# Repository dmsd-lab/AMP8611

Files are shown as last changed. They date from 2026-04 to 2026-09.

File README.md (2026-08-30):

### AMP8611 - Integrated class AB Stereo Power Amplifier

Open hardware project under CERN-OHL-S v2 license
 
Amplifier combining a 2-channel input selector, 
PGA2311 digital volume control and 45W per-channel LM3886 output stages.  

Full documentation (description pdf, Kicad project schematic and PCB, Gerber files, BOM, STM32 firmware) is available in the repository.

**Key Specifications**:
- Input resistance: 10kΩ;  
- Nominal input voltage: 0.85Vrms;  
- Maximum input voltage: 2.5Vrms;  
- Input Channels isolation: 95dB;  
- Maximum output power: 2 x 45W RMS (1kHz sinusoidal, 4ohm load);  
- Bandwidth (-3dB): 20Hz – 90kHz;  
- Volume control: -80 to +12dB;  
- Dimensions: 240 x 265 x 65 mm (80 mm including feet);  
- Weight: 4.0 kg.

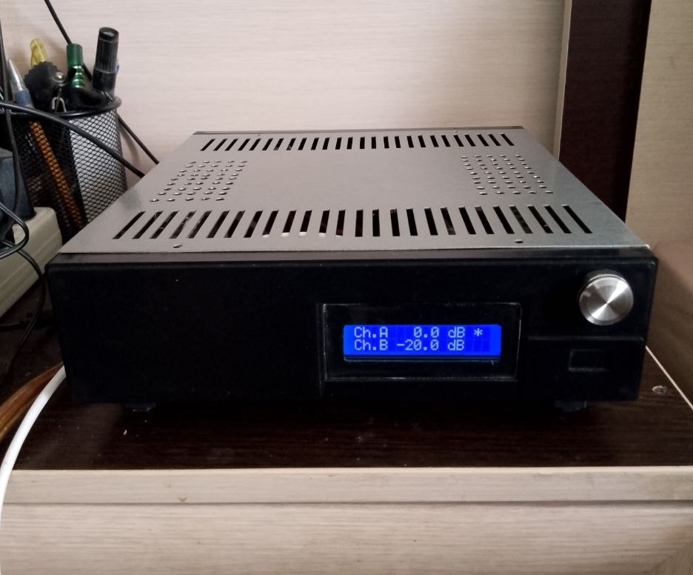
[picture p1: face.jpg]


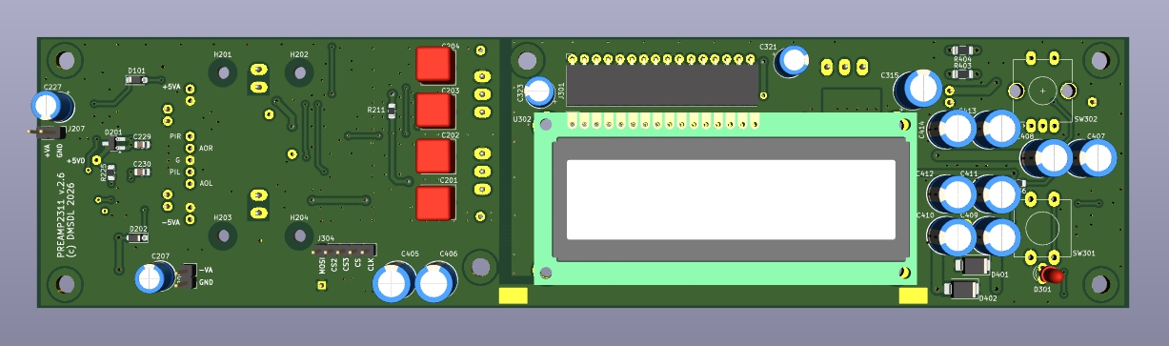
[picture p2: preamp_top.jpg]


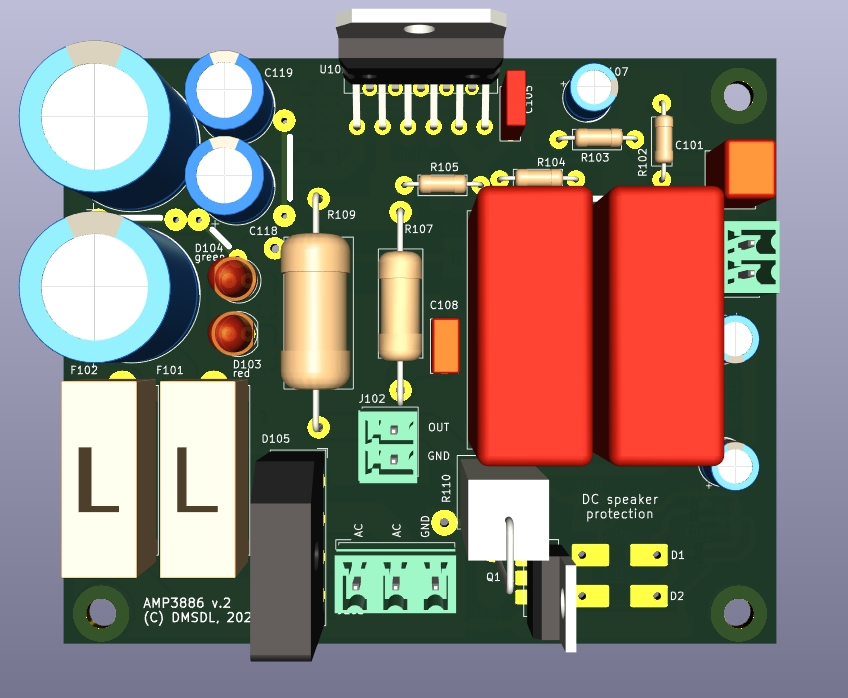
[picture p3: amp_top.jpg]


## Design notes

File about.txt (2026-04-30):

Integrated Stereo Power Amplifier with a 2-channel input selector, PGA2311 digital volume control and LM3886 power stages

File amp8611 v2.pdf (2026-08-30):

AMP8611 - Compact Integrated Stereo Power Amplifier

V.2.6
(c) DMSDL, 2026

Open hardware project released under CERN-OHL-S v2 license

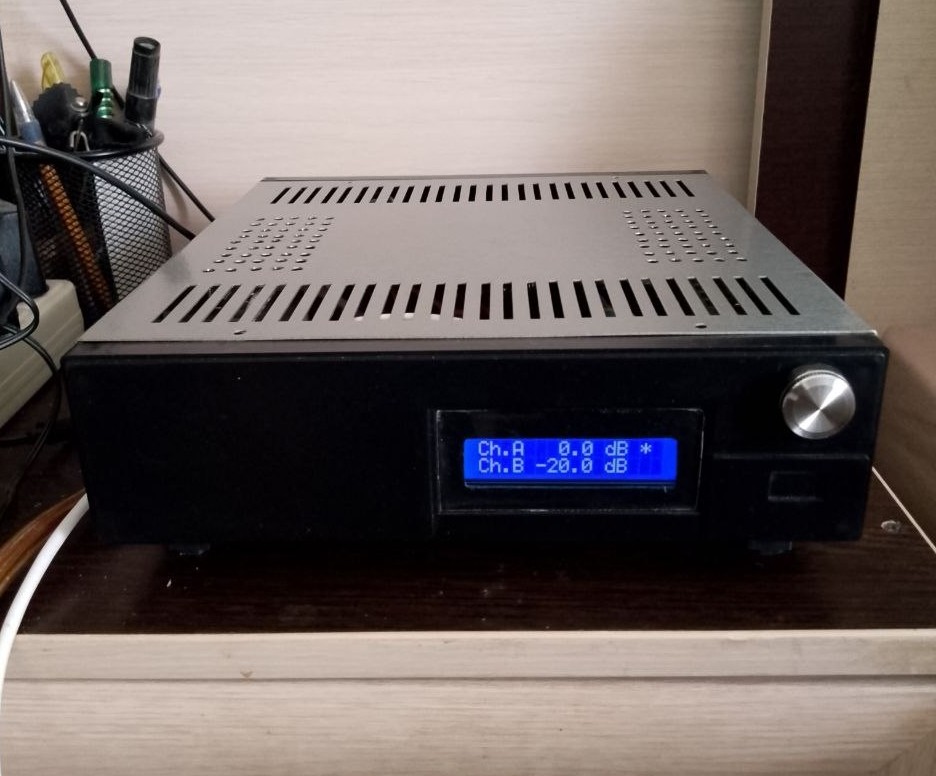
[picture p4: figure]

Amplifier combining a 2-channel input selector, high-performance PGA2311 digital volume control and LM3886 power stages.

Key Specifications:
Input resistance: 10kΩ;
Nominal input voltage: 0.85Vrms;
Maximum input voltage: 2.5Vrms;
Input Channels isolation: 95dB;
Maximum output power: 2 x 45W RMS (1kHz sinusoidal, 4ohm load); Bandwidth (-3dB): 20Hz – 90kHz;
Volume control: -80 to +12dB;
Dimensions: 240 x 265 x 65 mm (80 mm including feet);
Weight: 4.0 kg.

Full documentation (description PDF, schematic, PCB layout, Gerber files, BOM and firmware) is available in the repository https://github.com/dmsd-lab/AMP8611.

Preamplifier board PREAMP2311

Preamplifier based on PGA2311 - high-performance stereo volume control for professional and high-end consumer systems.
Input channel selector based on 74HCT4052 and OPA1678 in an ultra-low-distortion, seriesshunt current-mode configuration.
Bipolar power supply based on LM317L and LM337L linear regulators.
STM32G070 MCU, 2x16 LCD (with lowering backlight brightness after user inactivity)and rotary encoder with button for user interface (input channel selection, volume control).
Supports integration of controlled forced cooling and a digital tone control module.

Key Specifications:
Power supply: 2x(7 – 11V) AC or +-(8 – 14)V DC, 3W;
Input resistance: 10kΩ;
Maximum input voltage: 2.5Vrms;
Output offset voltage (gain 0dB), maximum: +-2.5mV;
Bandwidth (-3dB): 10Hz – 350kHz;
Channel isolation: 95dB;
Volume control: -80 to +12dB (−95.5 dB to +31.5 dB firmware limited); PCB dimensions: 234 x 58mm.

Firmware is developed with STM32CubeIDE.
The volume control step configuration is as follows:
−80 to −40dB - 5dB steps;
−40 to 0dB - 2dB steps;
0 to +12dB - 0.5dB steps.

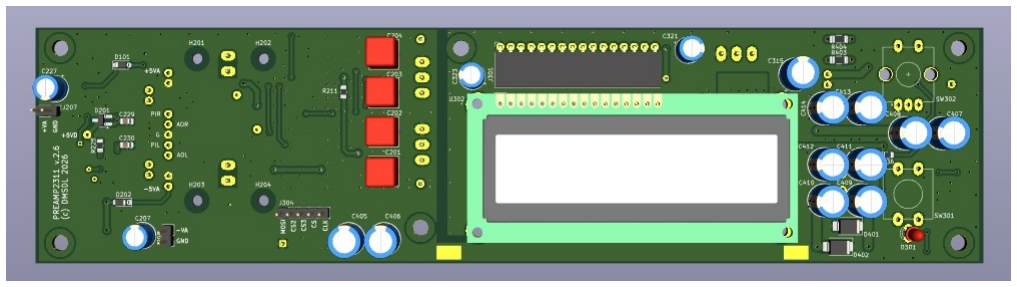
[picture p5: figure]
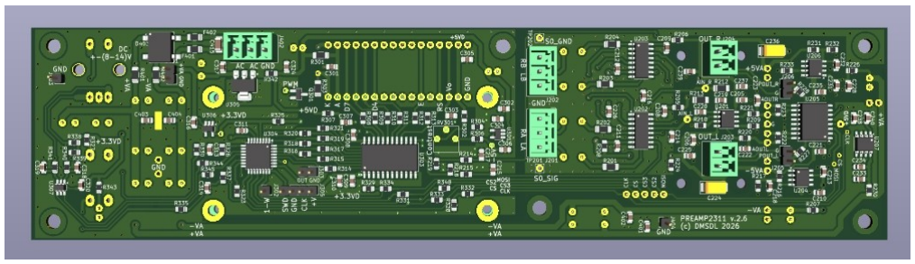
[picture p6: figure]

PREAMP2311 signal stage schematic

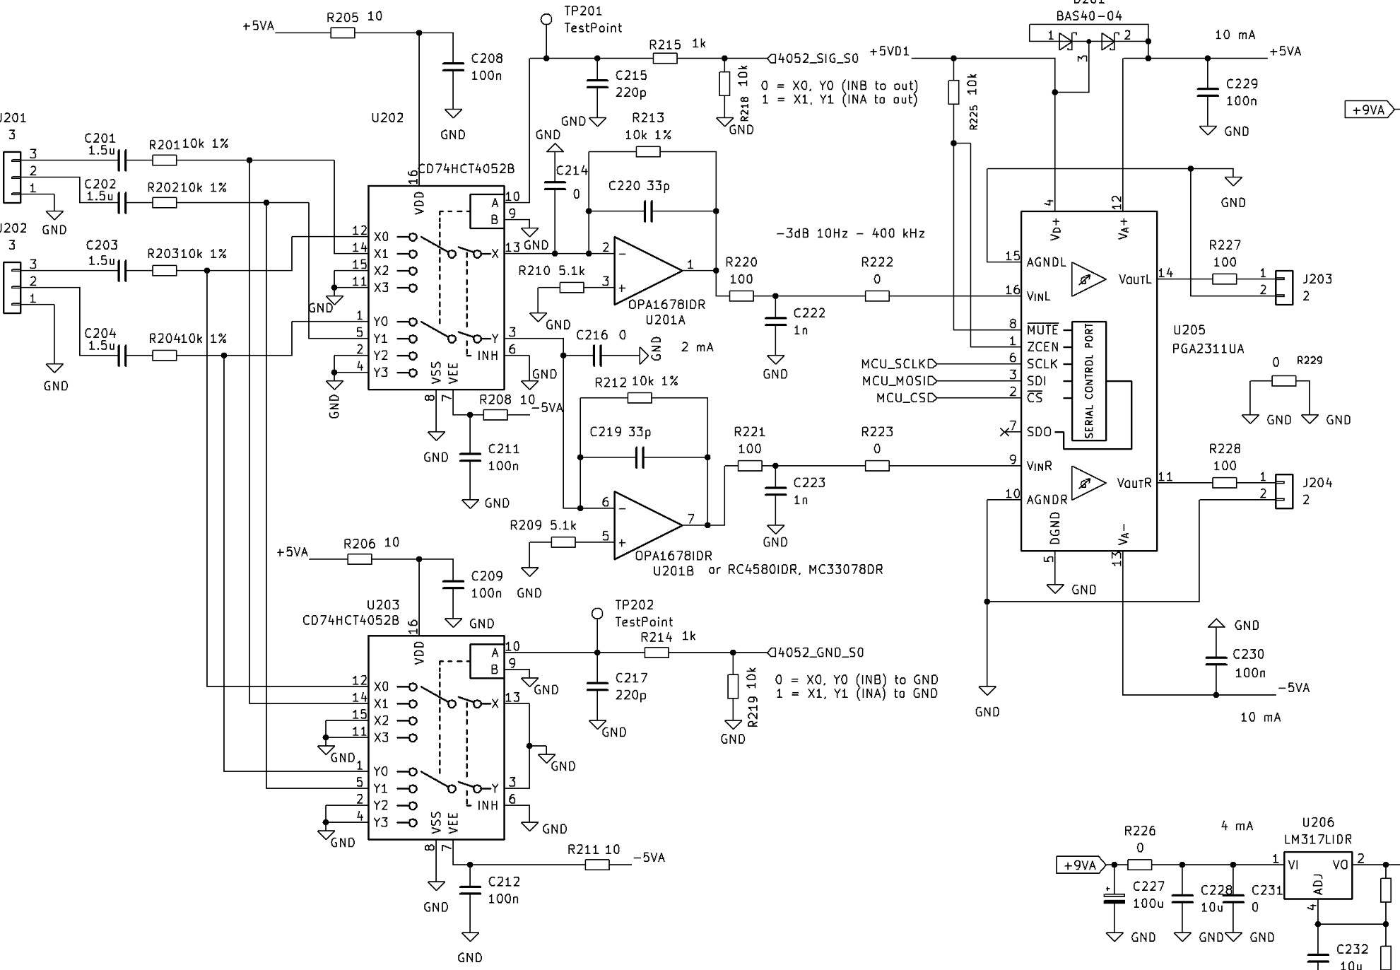
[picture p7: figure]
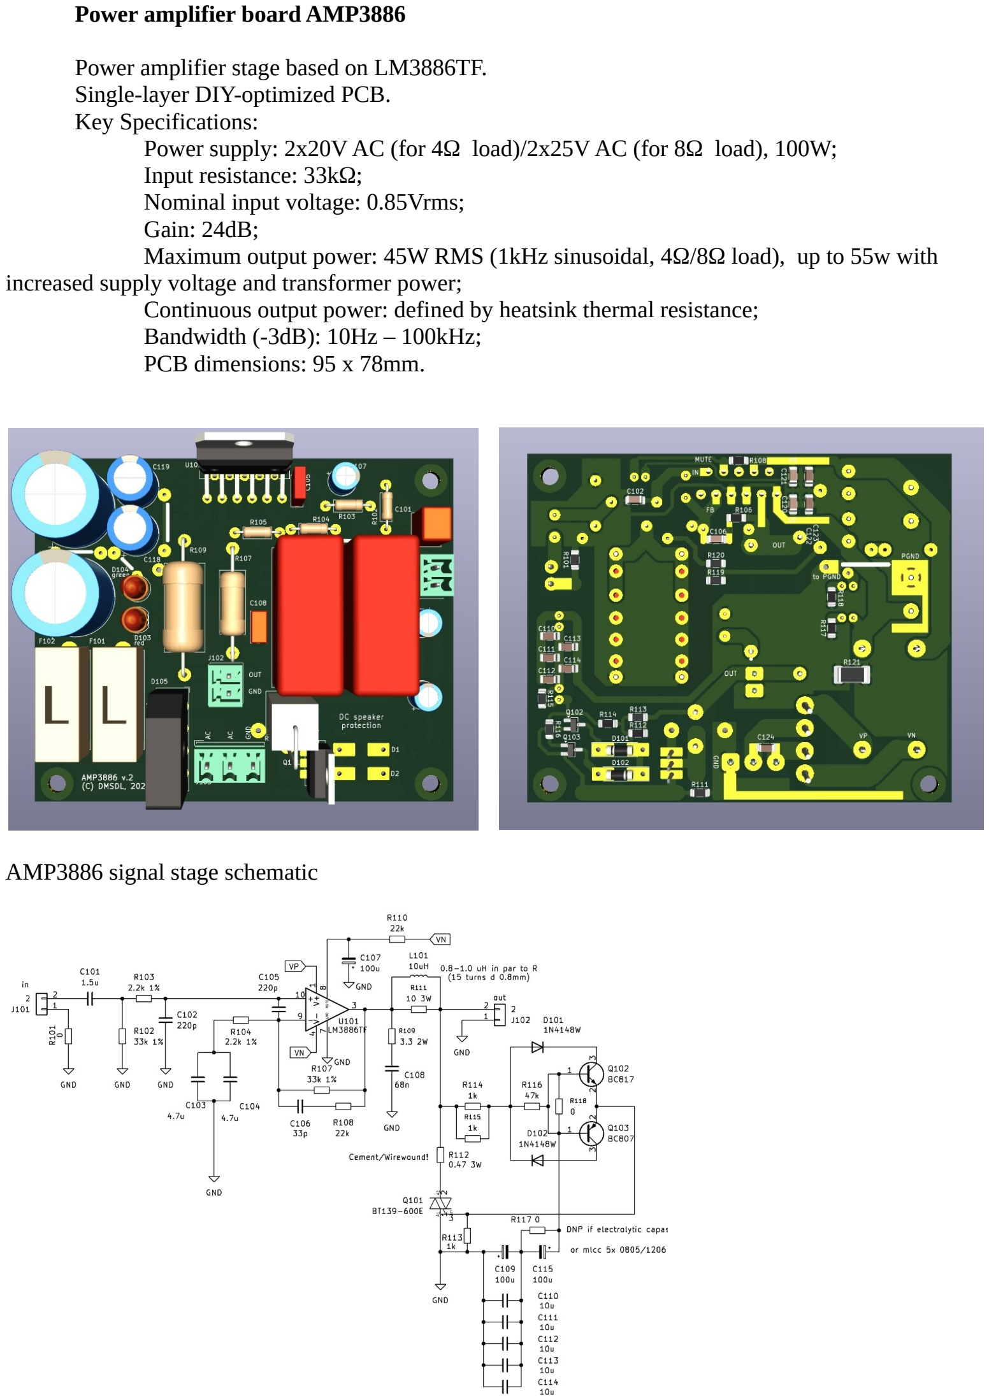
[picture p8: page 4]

Power amplifier board AMP3886

Power amplifier stage based on LM3886TF.
Single-layer DIY-optimized PCB.
Key Specifications:
Power supply: 2x20V AC (for 4Ω load)/2x25V AC (for 8Ω load), 100W; Input resistance: 33kΩ;
Nominal input voltage: 0.85Vrms;
Gain: 24dB;
Maximum output power: 45W RMS (1kHz sinusoidal, 4Ω/8Ω load), up to 55w with increased supply voltage and transformer power; Continuous output power: defined by heatsink thermal resistance;
Bandwidth (-3dB): 10Hz – 100kHz;
PCB dimensions: 95 x 78mm.

AMP3886 signal stage schematic

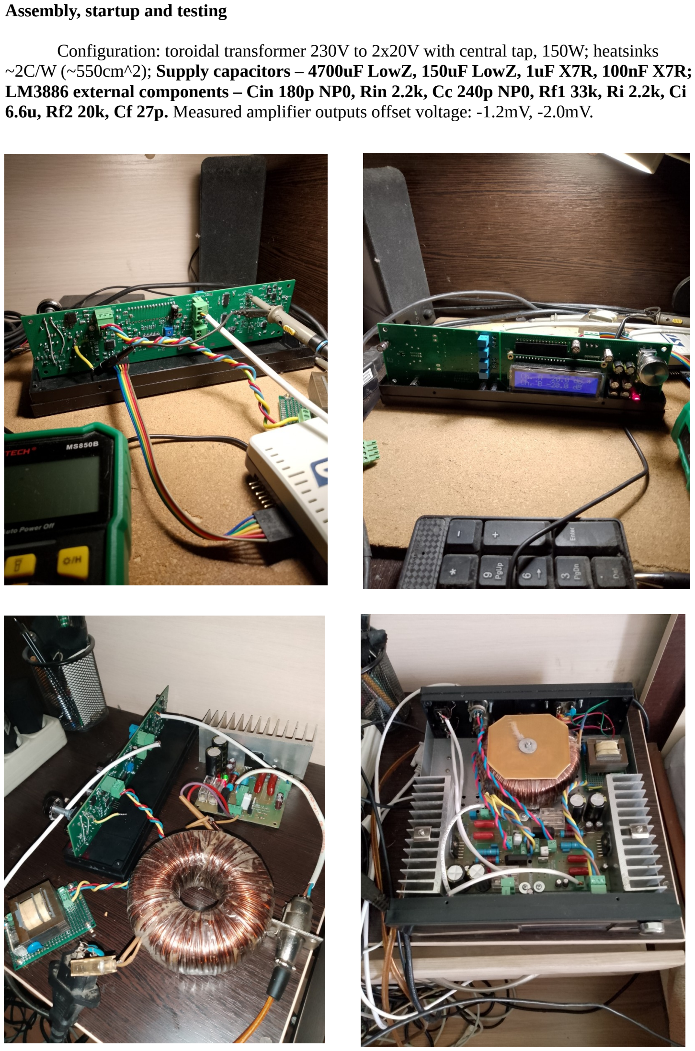
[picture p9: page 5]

Assembly, startup and testing

Configuration: toroidal transformer 230V to 2x20V with central tap, 150W; heatsinks ~2C/W (~550cm^2); Supply capacitors – 4700uF LowZ, 150uF LowZ, 1uF X7R, 100nF X7R; LM3886 external components – Cin 180p NP0, Rin 2.2k, Cc 240p NP0, Rf1 33k, Ri 2.2k, Ci 6.6u, Rf2 20k, Cf 27p. Measured amplifier outputs offset voltage: -1.2mV, -2.0mV.

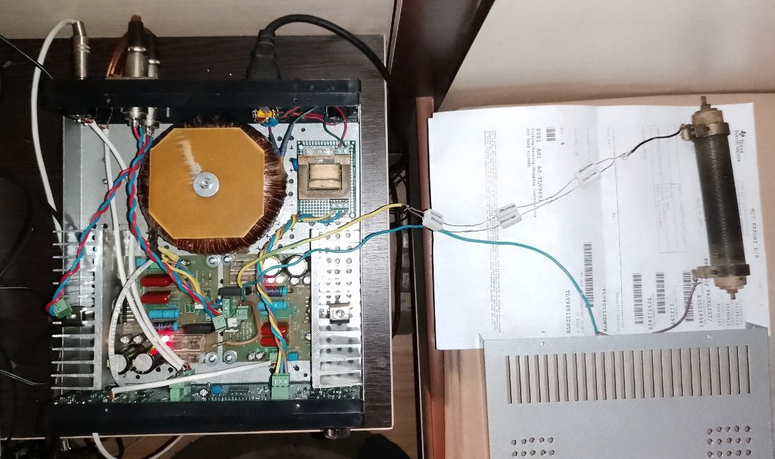
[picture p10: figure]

Caution: the protection circuit is provided as an optional safeguard. Its operation should be validated before soldering the amplifier IC.

Such a circuit was used in a Soviet amplifier “Орбита УМ-002”.

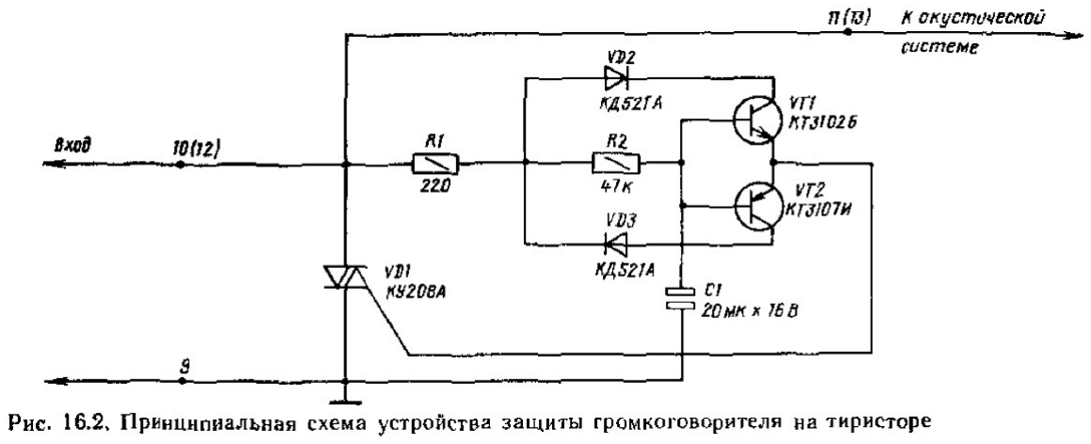
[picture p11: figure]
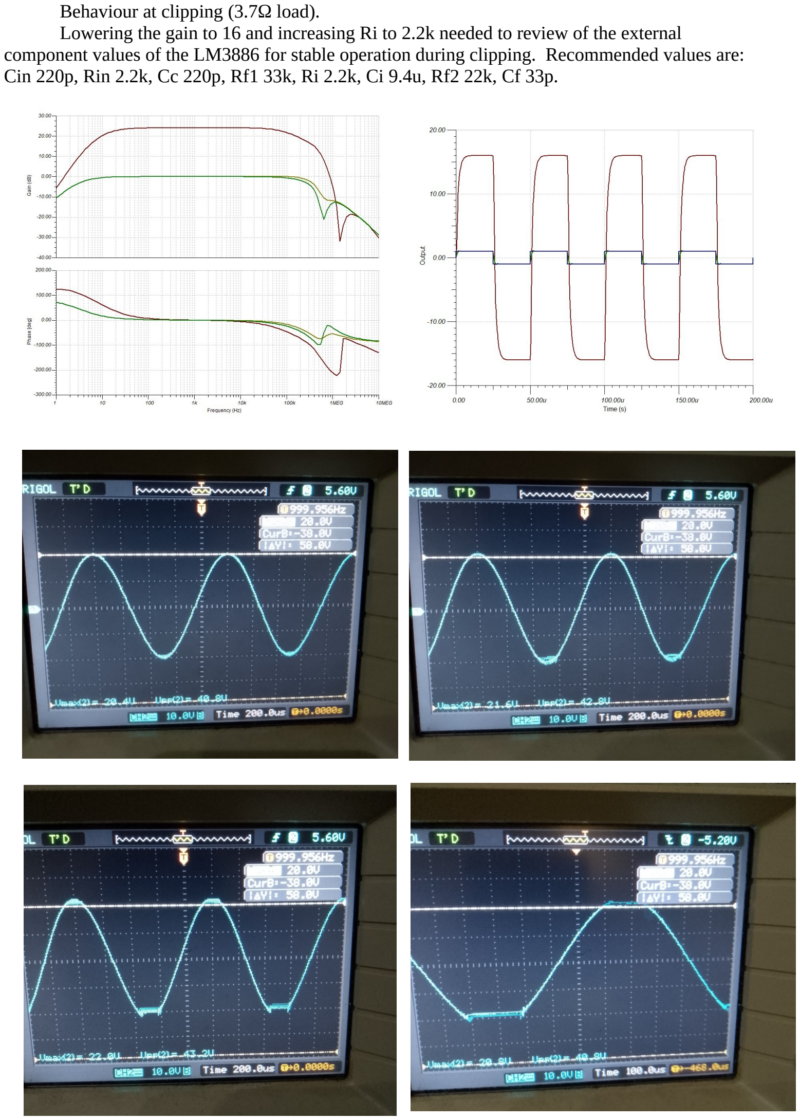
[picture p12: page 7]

Behaviour at clipping (3.7Ω load).
Lowering the gain to 16 and increasing Ri to 2.2k needed to review of the external component values of the LM3886 for stable operation during clipping. Recommended values are: Cin 220p, Rin 2.2k, Cc 220p, Rf1 33k, Ri 2.2k, Ci 9.4u, Rf2 22k, Cf 33p.

Output power test (3.7Ω load, 1kHz burst 20ms, 100Hz burst 100ms).

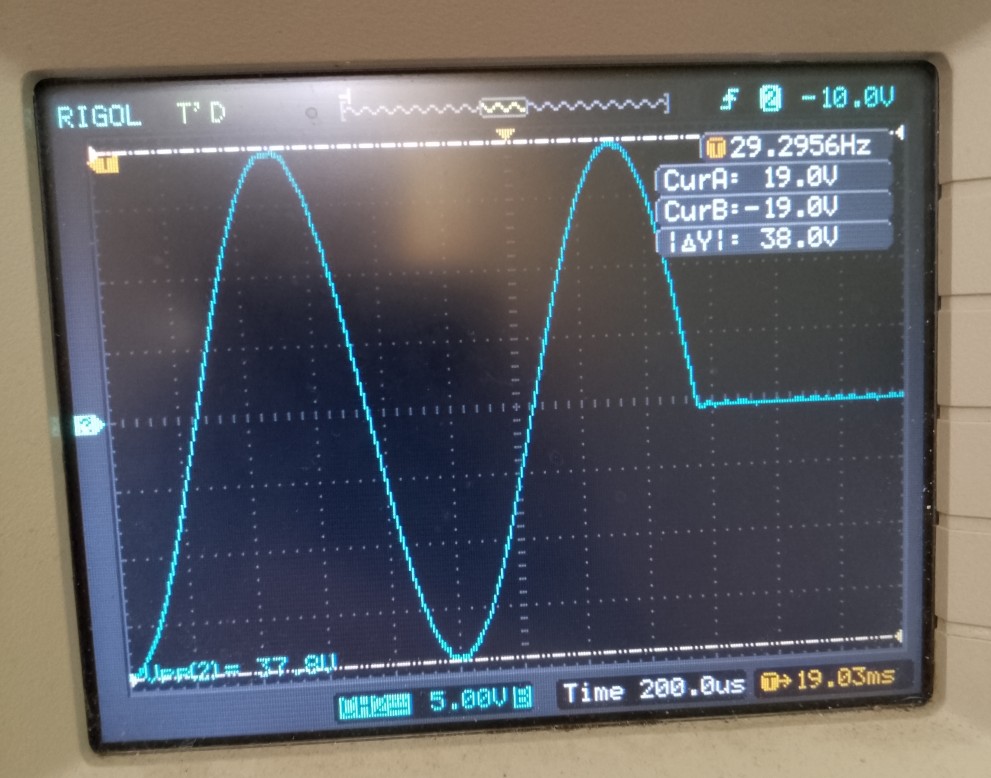
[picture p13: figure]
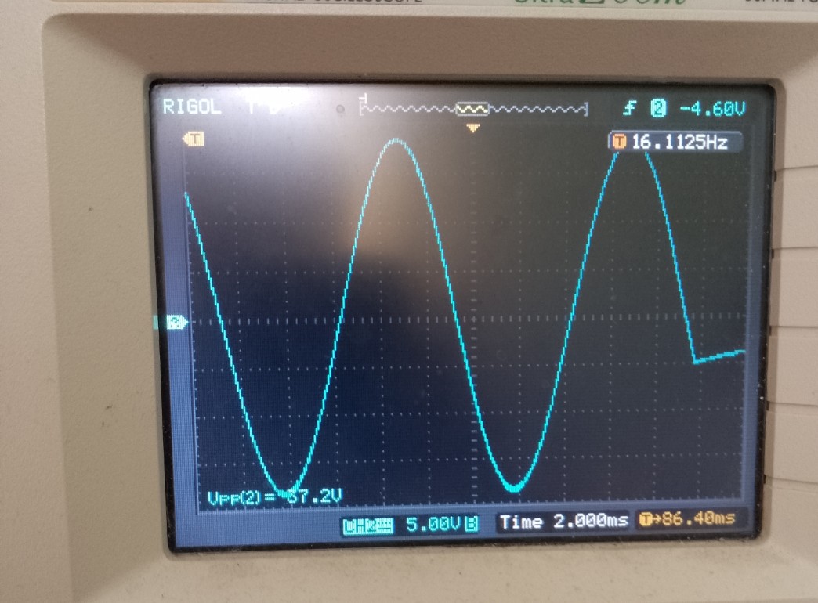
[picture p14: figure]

Musical signal test (3.7Ω load, PC audio output level 100% - 1V RMS when sinusoidal signal, volume control at 0dB).

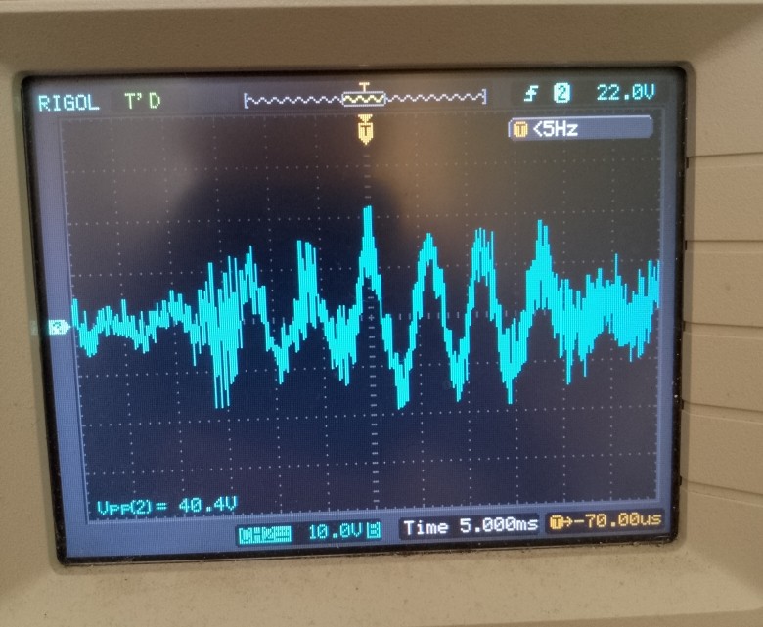
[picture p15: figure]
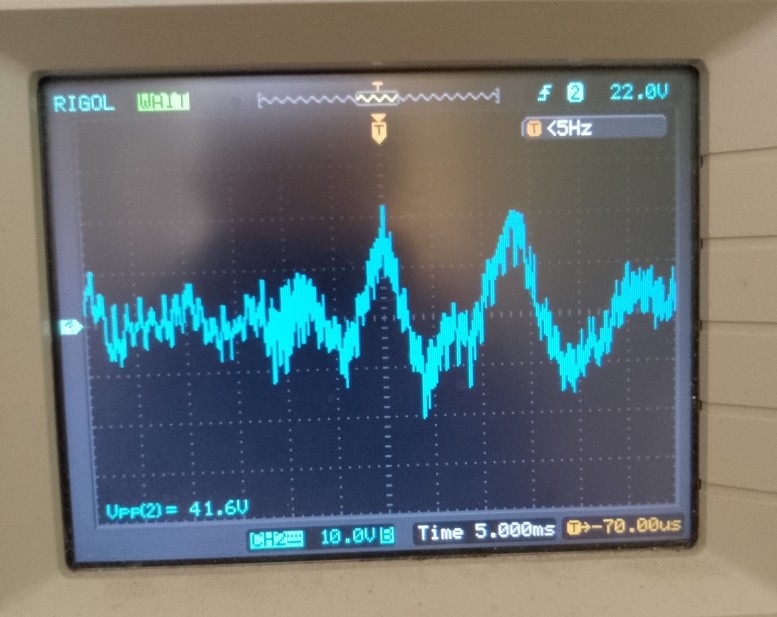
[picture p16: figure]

After 30 minutes of testing with a high density music signal (low crest factor) in a closed enclosure, ambient temperature 25C, the measured temperatures were:
- heatsink near the IC 75C;
- screw mounting the IC to the heatsink 80C.
In this mode, the amplifier already rarely clips the output signal at about 20V depending on the shape and power of the signal.
In the same operating mode, when driving a 4-ohm loudspeaker system, the temperatures is 10 degrees lower.
The amplifier is subjectively quiet: no audible mains hum or broadband noise at 50 cm from a 85dBw/m midbass driver in a quiet environment (volume at 0dB, input unconnected or PC output in sleep mode). With an active PC audio output, broadband noise becomes noticeable; at a volume setting of −10dB, the noise is barely distinguishable from the unconnected-input condition.

A working prototype (v. 1) was built and evaluated. The design met the intended specifications and no functional issues were observed.
The hardware released (v. 2) is a minor optimized revision of the prototype with no conceptual or architectural changes. A list of significant modifications is provided below.

Change log of preamplifier v.2.0 - 2.6:
1. Added resistor from the buffer op-amp non-inverting input to ground to compensate offset for op-amps with relatively high input bias currents;
2. Added MCU I/O for the 1-Wire interface, 3 output lines for control and 1 dedicated input for a button;
3. Removed the separate 3.3V voltage regulator for the 74LVC8T245 driver;
4. Added TVS diodes to the power input;
5. Added series resistors (10 - 100Ω) in the power lines of the multiplexers;
6. Added capacitor footprints to the multiplexer output (0-220pF for HF input noise and charge injection attenuation);
7. Reverse diode from output to input added to the LM317L and LM337L due to increased output capacitor value.

Change log of power amplifier v.2:
1. Added MLC capacitor footprints to the protection circuitry as alternative for electrolytic;
2. Pin 7 connected to SGND instead of connection to PGND.

Alternative components:
CD74HCT4052 – SOIC-16 CD74HC4052, 74HCT4052, 74HC4052, MC74HC4052A, MAX4052, MAX4582;
OPA1678IDR – OPA1688IDR, (https://www.ti.com/product/OPA1688/part-details/OPA1688ID) RC4580IDR, MC33078DR or any other with acceptable noise and distortion level (preferably with a lower overall output offset voltage);
TLV1117-50IDC – LM1117MPX-5.0, 5V SOT- 223 LD1117, NCP1117; TPS60403DBV – TPS60400DBV, TPS60401DBV, TPS60402DBV. Not needed if LCD offset voltage is positive.
SN74LVC8T245DW – SN74LVCC3245ADW;
SN74LVC2G17DBV – SN74LVC2G14DBV, 74HC2G17GV, 74HC2G14GV; 6800uF 35V 105C - 4700uF 35V 105C Low impedance.

Sources:
https://www.ti.com/product/LM3886
https://www.ti.com/product/PGA2311
https://www.ti.com/product/OPA1678

“Analog Switches and Multiplexers Basics” https://www.analog.com/media/en/trainingseminars/tutorials/MT-088.pdf (https://www.analog.com/media/en/training-seminars/tutorials/MT-088.pdf)
Douglas Self “Small signal audio design”, chapter 21 http://www.douglas-self.com/ampins/books/ssad3.htm
Samuel Groner “Operational amplifier distortion” 2009 https://audioxpress.com/article/modern-op-amp-distortion-tests-part-1-bjt-input-deviceshttps://audioxpress.com/article/modern-op-amp-distortion-tests-part-2-a-few-mo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 (https://audioxpress.com/article/modern-op-amp-distortion-tests-part-2-a-few-more-bjt-types-and-jfet-devices)
Атаев, Болотников “Функциональные узлы усилителей высококачественного звуковоспроизведения” 1989, chapter 16.3.
Rod Elliot, Crowbar Speaker Protection https://sound-au.com/project120.htm

© DMSDL, 2026
CERN-OHL-S v2 license

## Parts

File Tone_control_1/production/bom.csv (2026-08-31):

Designator | Footprint | Quantity | Value | LCSC Part #
C101, C102, C103, C105, C106, C107, C108, C111, C113, C124, C125, C134, C135 | 0805 | 13 | 100n
C104, C112 | 0805 | 2 | 10u
C109, C110 | CP_EIA-6032-20_AVX-F_HandSolder | 2 | 33u
C114, C115, C126, C129, C132, C133 | 0805 | 6 | 220p
C116, C117, C118, C120 | 0805 | 4 | 33p
C119, C121 | C_Rect_L7.5mm_W6.5mm_P5.00mm | 2 | 1,5u
C122, C123 | 0805 | 2 | 10n
C127, C128, C130, C131 | 1206 | 4 | 100n
D101, D102 | D_SOD-123 | 2 | 1N5819
J101 | PinHeader_1x01_P2.54mm_Vertical | 1 | Conn_01x01
J102 | PinSocket_1x12_P2.54mm_Vertical | 1 | Conn_01x05
J103 | PinSocket_1x05_P2.54mm_Vertical | 1 | Conn_01x05
R101, R102, R104, R106, R109, R110, R111, R112, R113, R114, R117, R118, R120, R122, R124, R126 | 0805 | 16 | 10k
R103, R105 | 0805 | 2 | 15k
R107, R108 | 0805 | 2 | 100
R115, R116, R119, R121, R123, R125 | 0805 | 6 | 3,3k
U101, U102, U103 | SOIC-8_3.9x4.9mm_P1.27mm | 3 | OPA1678
U104 | SOT-23-5_HandSoldering | 1 | TLV9051xDBV
U105, U106 | TSSOP-14_4.4x5mm_P0.65mm | 2 | MCP4261

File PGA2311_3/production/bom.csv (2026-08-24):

Designator | Footprint | Quantity | Value | LCSC Part #
C201, C202, C203, C204 | C_Rect_L7.2mm_W7.2mm_P5.00mm_FKS2_FKP2_MKS2_MKP2 | 4 | 1.5u
C205, C206, C208, C209, C211, C212, C221, C225, C226, C229, C230, C235, C237, C238, C239, C303, C309, C310, C311, C312, C313, C314, C318, C319, C320 | 0805 | 25 | 100n
C207, C227, C321, C323 | CP_Radial_D6.3mm_P2.50mm | 4 | 100u
C210, C218, C228, C232, C233, C240, C301, C302, C304, C305, C306, C307, C308, C316, C317, C322, C324, C401, C402, C403, C404 | 0805 | 21 | 10u
C213, C214, C216, C231, C234, R207, R222, R223, R226, R230, R304, R325 | 0805 | 12 | 0
C215, C217 | 0805 | 2 | 220p
C219, C220 | 0805 | 2 | 33p
C222, C223 | 0805 | 2 | 1n
C224, C236 | CP_EIA-6032-20_AVX-F_HandSolder | 2 | 33u
C315, C405, C406, C407, C408, C409, C410, C411, C412, C413, C414 | CP_Radial_D8.0mm_P3.50mm | 11 | 220u
C415 | 1206 | 1 | 100n
D101, D202 | D_SOD-123 | 2 | 1N5819
D201 | SOT-23_Handsoldering | 1 | BAS40-04
D301 | LED_D3.0mm | 1 | LED_GREEN
D401, D402 | D_SMB | 2 | SMAJ15.0A
D403 | Diode_Bridge_OnSemi_SDIP-4L | 1 | DF01S
F401, F402 | 1206 | 2 | MF-NSMF012-2
J201, J202, J402 | PhoenixContact_MCV_1,5_3-G-3.81_1x03_P3.81mm_Vertical | 3 | 3
J203, J204 | PhoenixContact_MCV_1,5_2-G-3.81_1x02_P3.81mm_Vertical | 2 | 2
J205, J206, J207, J208 | PinHeader_1x02_P2.54mm_Vertical | 4 | 2
J301 | PinSocket_1x16_P2.54mm_Horizontal | 1 | Conn_01x16
J302, J403, J404 | PinHeader_1x01_P2.54mm_Vertical | 3 | 1
J303 | PinHeader_1x02_P2.54mm_Vertical | 1 | Conn_01x02
J304 | PinHeader_1x05_P2.54mm_Vertical | 1 | 4
J305 | PinHeader_1x04_P2.54mm_Vertical | 1 | 4
J401 | PinHeader_1x02_P2.54mm_Vertical | 1 | 1
Q301 | SOT-23_Handsoldering | 1 | BC817-40
R201, R202, R203, R204, R212, R213 | 1206 | 6 | 10k 1%
R205, R206, R227, R228, R308, R309, R310, R311, R312, R313, R314, R315, R316, R317, R318, R319, R320, R321 | 0805 | 18 | 100
R208, R211 | 0805 | 2 | 10
R209, R210 | 0805 | 2 | 5.1k
R214, R215, R224, R233, R323, R326, R327, R331, R332, R333, R334, R336, R337, R338, R339, R344, R345, R348 | 0805 | 18 | 1k
R216, R231 | 0805 | 2 | 330 1%
R217, R232 | 0805 | 2 | 1k 1%
R218, R219, R225, R328, R329, R330, R335, R340, R341, R346, R347, R349 | 0805 | 12 | 10k
R220, R221, R343 | 0805 | 3 | 220
R301, R401, R402 | 1206 | 3 | 1
R302, R306 | 0805 | 2 | 2.7k
R303 | 1206 | 1 | 100
R305, R322, R324 | 0805 | 3 | 2,7k
R307, R342 | 0805 | 2 | 0.33
R403, R404 | 1206 | 2 | 0
RV301 | Potentiometer_Vishay_T73YP_Vertical | 1 | KLS4-3362P 5.1k
SW301 | SW_PUSH-12mm | 1 | SW_Push
SW302 | RotaryEncoder_Alps_EC12E-Switch_Vertical_H20mm_CircularMountingHoles | 1 | Encoder PEC11R
TP201, TP202 | TestPoint_THTPad_2.0x2.0mm_Drill1.0mm | 2 | TestPoint
U201 | SOIC-8_3.9x4.9mm_P1.27mm | 1 | OPA1678IDR
U202, U203 | SOIC-16_3.9x9.9mm_P1.27mm | 2 | CD74HCT4052
U204 | SOIC-8_3.9x4.9mm_P1.27mm | 1 | LM337LM
U205 | SOIC-16W_7.5x10.3mm_P1.27mm | 1 | PGA2311UA
U206 | SOIC-8_3.9x4.9mm_P1.27mm | 1 | LM317LIDR
U207 | SOIC-8_3.9x4.9mm_P1.27mm | 1 | UA78L05AIDR
U301 | SOT-23-5_HandSoldering | 1 | TPS60403DBV
U302 | WC1602A | 1 | WH1602B
U303 | SOIC-24W_7.5x15.4mm_P1.27mm | 1 | SN74LVC8T245DW
U304 | LQFP-32_7x7mm_P0.8mm | 1 | STM32G070KBT6
U305 | SOT-223-3_TabPin2 | 1 | TLV1117-50IDC
U306 | SOT-23-5_HandSoldering | 1 | LP2985-33DBV
U307 | SOT-23-6_Handsoldering | 1 | SN74LVC2G17DBV

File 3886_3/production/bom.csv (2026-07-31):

Designator | Footprint | Quantity | Value | LCSC Part #
C101 | C_Rect_L7.5mm_W6.5mm_P5.00mm | 1 | 1.5u
C102 | 1206 | 1 | 220p
C103, C104 | C_Rect_L31.5mm_W13.0mm_P27.50mm_MKS4 | 2 | 4.7u
C105 | C_Rect_L7.0mm_W2.5mm_P5.00mm | 1 | 220p
C106 | 1206 | 1 | 33p
C107, C109, C115 | CP_Radial_D6.3mm_P2.50mm | 3 | 100u
C108 | C_Rect_L7.0mm_W3.5mm_P5.00mm | 1 | 68n
C110, C111, C112, C113, C114 | 1206 | 5 | 10u
C116, C117 | CP_Radial_D18.0mm_P7.50mm | 2 | 6800u
C118, C119 | CP_Radial_D10.0mm_P5.00mm | 2 | 470u
C120, C121 | 1206 | 2 | 100n
C122, C123 | 1206 | 2 | 1u
C124 | 1206 | 1 | 100n 100V
D101, D102 | D_MELF-RM10_Universal_Handsoldering | 2 | 1N4148W
D103 | LED_D5.0mm | 1 | LED red
D104 | LED_D5.0mm | 1 | LED green
D105 | Diode_Bridge_Vishay_KBU | 1 | KBU1010
F101, F102 | Fuseholder_Cylinder-5x20mm_Stelvio-Kontek_PTF78_Horizontal_Open | 2 | 3A
J101, J102 | PhoenixContact_MCV_1,5_2-G-3.81_1x02_P3.81mm_Vertical | 2 | 2
J103 | PhoenixContact_MCV_1,5_3-G-5.08_1x03_P5.08mm_Vertical | 1 | 3
Q101 | TO-220-3_Vertical | 1 | BT139-600E
Q102 | SOT-23_Handsoldering | 1 | BC817
Q103 | SOT-23_Handsoldering | 1 | BC807
R101, R115, R116 | 1206 | 3 | 0
R102, R105 | R_Axial_DIN0207_L6.3mm_D2.5mm_P10.16mm_Horizontal | 2 | 33k 1%
R103, R104 | R_Axial_DIN0207_L6.3mm_D2.5mm_P10.16mm_Horizontal | 2 | 2.2k 1%
R106, R108 | 1206 | 2 | 22k
R107 | R_Axial_DIN0614_L14.3mm_D5.7mm_P25.40mm_Horizontal | 1 | 3.3 2W
R109 | R_Axial_DIN0922_L20.0mm_D9.0mm_P30.48mm_Horizontal | 1 | 10 3W
R110 | R_Axial_Power_L25.0mm_W9.0mm_P7.62mm_Vertical | 1 | 0.47 3W
R111, R112, R113 | 1206 | 3 | 1k
R114 | 1206 | 1 | 47k
R117, R118 | 1206 | 2 | 10k
R119, R120 | 1206 | 2 | 1
R121 | 2512 | 1 | 0
U101 | TO-220-11_P3.4x5.08mm_StaggerOdd_Lead4.58mm_Vertical | 1 | LM3886TF

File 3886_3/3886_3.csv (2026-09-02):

Id | Designator | Footprint | Quantity | Designation | Supplier and ref
1 | R104,R103 | R_Axial_DIN0207_L6.3mm_D2.5mm_P10.16mm_Horizontal | 2 | 2.2k 1%
2 | C115,C109,C107 | CP_Radial_D6.3mm_P2.50mm | 3 | 100u
3 | C104,C103 | C_Rect_L31.5mm_W13.0mm_P27.50mm_MKS4 | 2 | 4.7u
4 | D105 | Diode_Bridge_Vishay_KBU | 1 | KBU1010
5 | J103 | PhoenixContact_MCV_1,5_3-G-5.08_1x03_P5.08mm_Vertical | 1 | 3
6 | D104 | LED_D5.0mm | 1 | LED green
7 | U101 | TO-220-11_P3.4x5.08mm_StaggerOdd_Lead4.58mm_Vertical | 1 | LM3886TF
8 | D103 | LED_D5.0mm | 1 | LED red
9 | R102,R105 | R_Axial_DIN0207_L6.3mm_D2.5mm_P10.16mm_Horizontal | 2 | 33k 1%
10 | R109 | R_Axial_DIN0922_L20.0mm_D9.0mm_P30.48mm_Horizontal | 1 | 10 3W
11 | Q101 | TO-220-3_Vertical | 1 | BT139-600E
12 | C108 | C_Rect_L7.0mm_W3.5mm_P5.00mm | 1 | 68n
13 | F101,F102 | Fuseholder_Cylinder-5x20mm_Stelvio-Kontek_PTF78_Horizontal_Open | 2 | 3A
14 | C119,C118 | CP_Radial_D10.0mm_P5.00mm | 2 | 470u
15 | C116,C117 | CP_Radial_D18.0mm_P7.50mm | 2 | 6800u
16 | R107 | R_Axial_DIN0614_L14.3mm_D5.7mm_P25.40mm_Horizontal | 1 | 3.3 2W
17 | R110 | R_Axial_Power_L25.0mm_W9.0mm_P7.62mm_Vertical | 1 | 0.47 3W
18 | J101,J102 | PhoenixContact_MCV_1,5_2-G-3.81_1x02_P3.81mm_Vertical | 2 | 2
19 | C105 | C_Rect_L7.0mm_W2.5mm_P5.00mm | 1 | 220p
20 | C101 | C_Rect_L7.5mm_W6.5mm_P5.00mm | 1 | 1.5u
21 | R120,R119 | R_1206_3216Metric_Pad1.30x1.75mm_HandSolder | 2 | 1
22 | C102 | C_1206_3216Metric_Pad1.33x1.80mm_HandSolder | 1 | 220p
23 | R115,R116,R101 | R_1206_3216Metric_Pad1.30x1.75mm_HandSolder | 3 | 0
24 | R117,R118 | R_1206_3216Metric_Pad1.30x1.75mm_HandSolder | 2 | 10k
25 | R108,R106 | R_1206_3216Metric_Pad1.30x1.75mm_HandSolder | 2 | 22k
26 | R114 | R_1206_3216Metric_Pad1.30x1.75mm_HandSolder | 1 | 47k
27 | C121,C120 | C_1206_3216Metric_Pad1.33x1.80mm_HandSolder | 2 | 100n
28 | C111,C110,C113,C114,C112 | C_1206_3216Metric_Pad1.33x1.80mm_HandSolder | 5 | 10u
29 | D102,D101 | D_MELF-RM10_Universal_Handsoldering | 2 | 1N4148W
30 | C123,C122 | C_1206_3216Metric_Pad1.33x1.80mm_HandSolder | 2 | 1u
31 | R113,R111,R112 | R_1206_3216Metric_Pad1.30x1.75mm_HandSolder | 3 | 1k
32 | Q102 | SOT-23_Handsoldering | 1 | BC817
33 | R121 | R_2512_6332Metric_Pad1.40x3.35mm_HandSolder | 1 | 0
34 | Q103 | SOT-23_Handsoldering | 1 | BC807
35 | C124 | C_1206_3216Metric_Pad1.33x1.80mm_HandSolder | 1 | 100n 100V
36 | C106 | C_1206_3216Metric_Pad1.33x1.80mm_HandSolder | 1 | 33p

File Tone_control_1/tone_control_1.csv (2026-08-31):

Id | Designator | Footprint | Quantity | Designation | Supplier and ref
1 | D101,D102 | D_SOD-123 | 2 | 1N5819
2 | U106,U105 | TSSOP-14_4.4x5mm_P0.65mm | 2 | MCP4261
3 | C112,C104 | C_0805_2012Metric_Pad1.18x1.45mm_HandSolder | 2 | 10u
4 | R124,R101,R120,R102,R113,R109,R114,R106,R110,R111,R118,R112,R117,R104,R122,R126 | R_0805_2012Metric_Pad1.20x1.40mm_HandSolder | 16 | 10k
5 | R103,R105 | R_0805_2012Metric_Pad1.20x1.40mm_HandSolder | 2 | 15k
6 | C124,C106,C111,C107,C108,C102,C103,C135,C101,C125,C134,C105,C113 | C_0805_2012Metric_Pad1.18x1.45mm_HandSolder | 13 | 100n
7 | R125,R121,R123,R119,R116,R115 | R_0805_2012Metric_Pad1.20x1.40mm_HandSolder | 6 | 3,3k
8 | U103,U101,U102 | SOIC-8_3.9x4.9mm_P1.27mm | 3 | OPA1678
9 | U104 | SOT-23-5_HandSoldering | 1 | TLV9051xDBV
10 | C120,C118,C116,C117 | C_0805_2012Metric_Pad1.18x1.45mm_HandSolder | 4 | 33p
11 | R107,R108 | R_0805_2012Metric_Pad1.20x1.40mm_HandSolder | 2 | 100
12 | C127,C130,C131,C128 | C_1206_3216Metric_Pad1.33x1.80mm_HandSolder | 4 | 100n
13 | C122,C123 | C_0805_2012Metric_Pad1.18x1.45mm_HandSolder | 2 | 10n
14 | J103 | PinSocket_1x05_P2.54mm_Vertical | 1 | Conn_01x05
15 | C133,C114,C126,C115,C132,C129 | C_0805_2012Metric_Pad1.18x1.45mm_HandSolder | 6 | 220p
16 | C110,C109 | CP_EIA-6032-20_AVX-F_HandSolder | 2 | 33u
17 | C121,C119 | C_Rect_L7.5mm_W6.5mm_P5.00mm | 2 | 1,5u
18 | J101 | PinHeader_1x01_P2.54mm_Vertical | 1 | Conn_01x01
19 | J102 | PinSocket_1x12_P2.54mm_Vertical | 1 | Conn_01x05

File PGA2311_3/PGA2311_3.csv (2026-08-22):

Id | Designator | Footprint | Quantity | Designation | Supplier and ref
1 | U302 | WC1602A | 1 | WH1602B
2 | J208,J207,J206,J205 | PinHeader_1x02_P2.54mm_Vertical | 4 | 2
3 | C321,C323,C227,C207 | CP_Radial_D6.3mm_P2.50mm | 4 | 100u
4 | SW301 | SW_PUSH-12mm | 1 | SW_Push
5 | C413,C410,C405,C412,C409,C315,C406,C411,C407,C414,C408 | CP_Radial_D8.0mm_P3.50mm | 11 | 220u
6 | R404,R403 | R_1206_3216Metric_Pad1.30x1.75mm_HandSolder | 2 | 0
7 | D301 | LED_D3.0mm | 1 | LED_GREEN
8 | D402,D401 | D_SMB | 2 | SMAJ15.0A
9 | C312,C229,C230,C206,C205,C310,C226,C238,C239,C209,C303,C318,C208,C211,C235,C314,C221,C225,C309,C311,C320,C237,C313,C319,C212 | C_0805_2012Metric_Pad1.18x1.45mm_HandSolder | 25 | 100n
10 | C322,C324,C228,C301,C403,C210,C401,C218,C302,C308,C240,C307,C404,C402,C232,C317,C306,C305,C233,C316,C304 | C_0805_2012Metric_Pad1.18x1.45mm_HandSolder | 21 | 10u
11 | R349,R225,R347,R346,R340,R341,R330,R219,R218,R335,R329,R328 | R_0805_2012Metric_Pad1.20x1.40mm_HandSolder | 12 | 10k
12 | R336,R224,R334,R332,R337,R214,R233,R331,R215,R339,R327,R345,R326,R323,R333,R344,R348,R338 | R_0805_2012Metric_Pad1.20x1.40mm_HandSolder | 18 | 1k
13 | SW302 | RotaryEncoder_Alps_EC12E-Switch_Vertical_H20mm_CircularMountingHoles | 1 | Encoder PEC11R
14 | C201,C204,C203,C202 | C_Rect_L7.2mm_W7.2mm_P5.00mm_FKS2_FKP2_MKS2_MKP2 | 4 | 1.5u
15 | R322,R324,R305 | R_0805_2012Metric_Pad1.20x1.40mm_HandSolder | 3 | 2,7k
16 | D201 | SOT-23_Handsoldering | 1 | BAS40-04
17 | R211,R208 | R_0805_2012Metric_Pad1.20x1.40mm_HandSolder | 2 | 10
18 | J304 | PinHeader_1x05_P2.54mm_Vertical | 1 | 4
19 | J301 | PinSocket_1x16_P2.54mm_Horizontal | 1 | Conn_01x16
20 | C219,C220 | C_0805_2012Metric_Pad1.18x1.45mm_HandSolder | 2 | 33p
21 | R232,R217 | R_0805_2012Metric_Pad1.20x1.40mm_HandSolder | 2 | 1k 1%
22 | U305 | SOT-223-3_TabPin2 | 1 | TLV1117-50IDC
23 | C222,C223 | C_0805_2012Metric_Pad1.18x1.45mm_HandSolder | 2 | 1n
24 | R313,R320,R312,R314,R228,R309,R227,R319,R315,R311,R316,R321,R308,R317,R318,R205,R206,R310 | R_0805_2012Metric_Pad1.20x1.40mm_HandSolder | 18 | 100
25 | C236,C224 | CP_EIA-6032-20_AVX-F_HandSolder | 2 | 22u
26 | C215,C217 | C_0805_2012Metric_Pad1.18x1.45mm_HandSolder | 2 | 220p
27 | J202,J402,J201 | PhoenixContact_MCV_1,5_3-G-3.81_1x03_P3.81mm_Vertical | 3 | 3
28 | C234,C213,C216,C214,C231 | C_0805_2012Metric_Pad1.18x1.45mm_HandSolder | 5 | 0
29 | R210,R209 | R_0805_2012Metric_Pad1.20x1.40mm_HandSolder | 2 | 5.1k
30 | U304 | LQFP-32_7x7mm_P0.8mm | 1 | STM32G070KBT6
31 | F402,F401 | Fuse_1206_3216Metric | 2 | MF-NSMF012-2
32 | J305 | PinHeader_1x04_P2.54mm_Vertical | 1 | 4
33 | D403 | Diode_Bridge_OnSemi_SDIP-4L | 1 | DF01S
34 | R201,R212,R202,R204,R203,R213 | R_1206_3216Metric_Pad1.30x1.75mm_HandSolder | 6 | 10k 1%
35 | U307 | SOT-23-6_Handsoldering | 1 | SN74LVC2G17DBV
36 | R220,R343,R221 | R_0805_2012Metric_Pad1.20x1.40mm_HandSolder | 3 | 220
37 | U303 | SOIC-24W_7.5x15.4mm_P1.27mm | 1 | SN74LVC8T245DW
38 | R303 | R_1206_3216Metric_Pad1.30x1.75mm_HandSolder | 1 | 100
39 | R342,R307 | R_0805_2012Metric_Pad1.20x1.40mm_HandSolder | 2 | 0.33
40 | J303 | PinHeader_1x02_P2.54mm_Vertical | 1 | Conn_01x02
41 | U301 | SOT-23-5_HandSoldering | 1 | TPS60403DBV
42 | R230,R222,R325,R207,R226,R304,R223 | R_0805_2012Metric_Pad1.20x1.40mm_HandSolder | 7 | 0
43 | R306,R302 | R_0805_2012Metric_Pad1.20x1.40mm_HandSolder | 2 | 2.7k
44 | U206 | SOIC-8_3.9x4.9mm_P1.27mm | 1 | LM317LIDR
45 | R216,R231 | R_0805_2012Metric_Pad1.20x1.40mm_HandSolder | 2 | 330 1%
46 | Q301 | SOT-23_Handsoldering | 1 | BC817-40
47 | R301,R402,R401 | R_1206_3216Metric_Pad1.30x1.75mm_HandSolder | 3 | 1
48 | J302,J403,J404 | PinHeader_1x01_P2.54mm_Vertical | 3 | 1
49 | TP201,TP202 | TestPoint_THTPad_2.0x2.0mm_Drill1.0mm | 2 | TestPoint
50 | U306 | SOT-23-5_HandSoldering | 1 | LP2985-33DBV
51 | RV301 | Potentiometer_Vishay_T73YP_Vertical | 1 | KLS4-3362P 5.1k
52 | C415 | C_1206_3216Metric_Pad1.33x1.80mm_HandSolder | 1 | 100n
53 | U207 | SOIC-8_3.9x4.9mm_P1.27mm | 1 | UA78L05AIDR
54 | U203,U202 | SOIC-16_3.9x9.9mm_P1.27mm | 2 | CD74HCT4052
55 | J204,J203 | PhoenixContact_MCV_1,5_2-G-3.81_1x02_P3.81mm_Vertical | 2 | 2
56 | J401 | PinHeader_1x02_P2.54mm_Vertical | 1 | 1
57 | U204 | SOIC-8_3.9x4.9mm_P1.27mm | 1 | LM337LM
58 | U205 | SOIC-16W_7.5x10.3mm_P1.27mm | 1 | PGA2311UA
59 | U201 | SOIC-8_3.9x4.9mm_P1.27mm | 1 | OPA1678IDR

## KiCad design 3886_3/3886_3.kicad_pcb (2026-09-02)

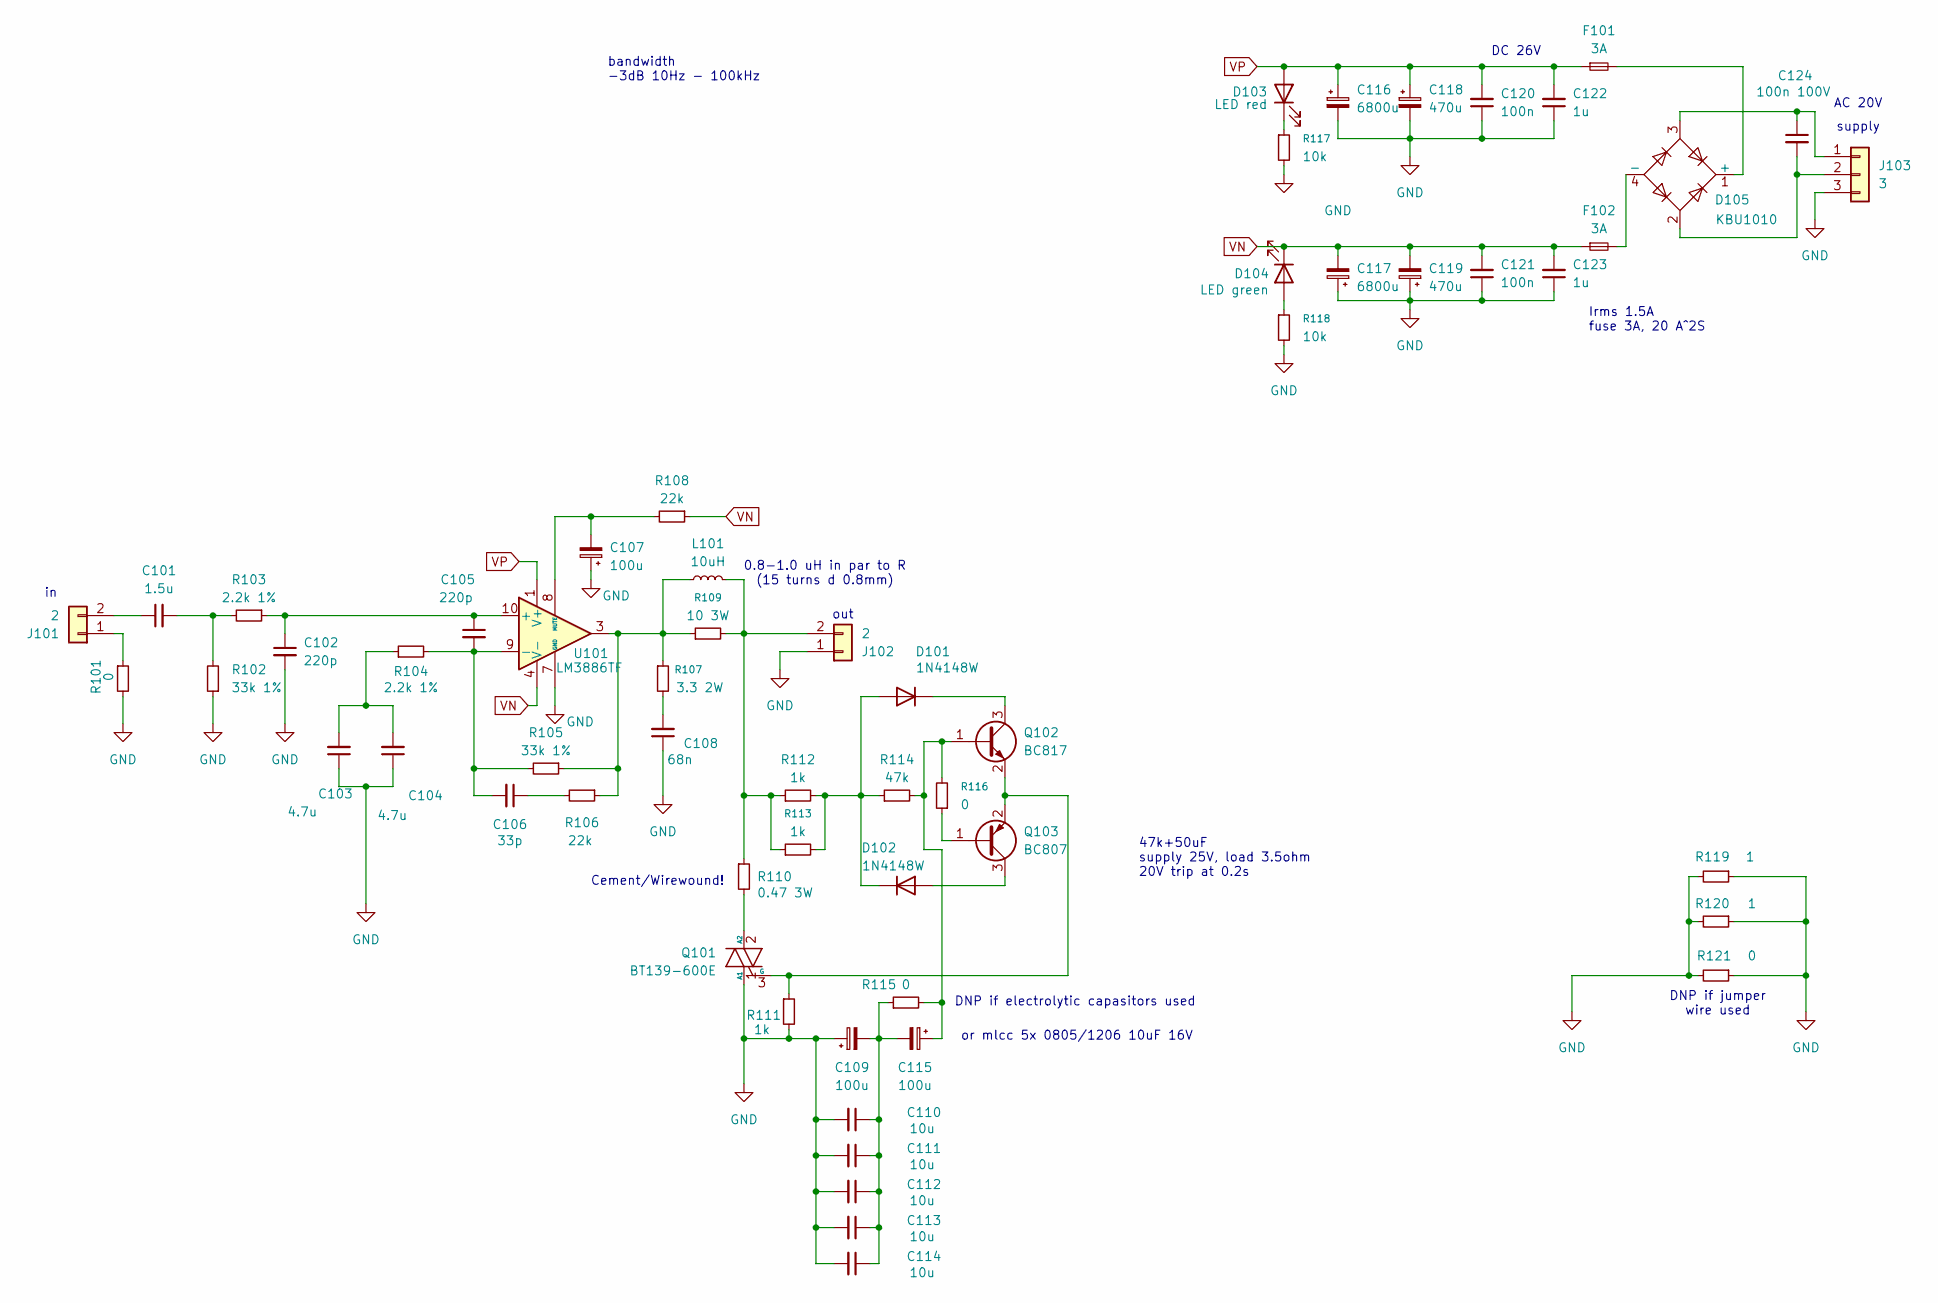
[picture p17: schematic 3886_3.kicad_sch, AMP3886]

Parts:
C101: 1.5u; C_Rect_L7.5mm_W6.5mm_P5.00mm
C102: 220p; C_1206_3216Metric_Pad1.33x1.80mm_HandSolder
C103, C104: 4.7u; C_Rect_L31.5mm_W13.0mm_P27.50mm_MKS4
C105: 220p; C_Rect_L7.0mm_W2.5mm_P5.00mm
C106: 33p; C_1206_3216Metric_Pad1.33x1.80mm_HandSolder
C107, C109, C115: 100u; CP_Radial_D6.3mm_P2.50mm
C108: 68n; C_Rect_L7.0mm_W3.5mm_P5.00mm
C110, C111, C112, C113, C114: 10u; C_1206_3216Metric_Pad1.33x1.80mm_HandSolder
C116, C117: 6800u; CP_Radial_D18.0mm_P7.50mm
C118, C119: 470u; CP_Radial_D10.0mm_P5.00mm
C120, C121: 100n; C_1206_3216Metric_Pad1.33x1.80mm_HandSolder
C122, C123: 1u; C_1206_3216Metric_Pad1.33x1.80mm_HandSolder
C124: 100n 100V; C_1206_3216Metric_Pad1.33x1.80mm_HandSolder
D101, D102: 1N4148W; D_MELF-RM10_Universal_Handsoldering
D103: LED red; LED_D5.0mm
D104: LED green; LED_D5.0mm
D105: KBU1010; Diode_Bridge_Vishay_KBU
F101, F102: 3A; Fuseholder_Cylinder-5x20mm_Stelvio-Kontek_PTF78_Horizontal_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
J101, J102: 2; PhoenixContact_MCV_1,5_2-G-3.81_1x02_P3.81mm_Vertical
J103: 3; PhoenixContact_MCV_1,5_3-G-5.08_1x03_P5.08mm_Vertical
L101: 10uH
Q101: BT139-600E; TO-220-3_Vertical
Q102: BC817; SOT-23_Handsoldering
Q103: BC807; SOT-23_Handsoldering
R101, R115, R116: 0; R_1206_3216Metric_Pad1.30x1.75mm_HandSolder
R102, R105: 33k 1%; R_Axial_DIN0207_L6.3mm_D2.5mm_P10.16mm_Horizontal
R103, R104: 2.2k 1%; R_Axial_DIN0207_L6.3mm_D2.5mm_P10.16mm_Horizontal
R106, R108: 22k; R_1206_3216Metric_Pad1.30x1.75mm_HandSolder
R107: 3.3 2W; R_Axial_DIN0614_L14.3mm_D5.7mm_P25.40mm_Horizontal
R109: 10 3W; R_Axial_DIN0922_L20.0mm_D9.0mm_P30.48mm_Horizontal
R110: 0.47 3W; R_Axial_Power_L25.0mm_W9.0mm_P7.62mm_Vertical
R111, R112, R113: 1k; R_1206_3216Metric_Pad1.30x1.75mm_HandSolder
R114: 47k; R_1206_3216Metric_Pad1.30x1.75mm_HandSolder
R117, R118: 10k; R_1206_3216Metric_Pad1.30x1.75mm_HandSolder
R119, R120: 1; R_1206_3216Metric_Pad1.30x1.75mm_HandSolder
R121: 0; R_2512_6332Metric_Pad1.40x3.35mm_HandSolder
U101: LM3886TF; TO-220-11_P3.4x5.08mm_StaggerOdd_Lead4.58mm_Vertical

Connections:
GND: C102.2, C103.1, C104.1, C107.1, C108.1, C109.1, C110.2, C111.2, C112.2, C113.2, C114.2, C116.2, C117.1, C118.2, C119.1, C120.1, C121.1, C122.1, C123.1, J102.1, J103.3, Q101.1 (A1), R101.2, R102.1, R111.2, R117.2, R118.2, R119.1, R119.2, R120.1, R120.2, R121.1, R121.2, U101.7 (GND)
unnamed: C101.2, R102.2, R103.2
unnamed: C103.2, C104.2, R104.1
unnamed: C106.1, R106.2
unnamed: C108.2, R107.2
unnamed: C109.2, C110.1, C111.1, C112.1, C113.1, C114.1, C115.2, R115.1
unnamed: D101.2 (A), D102.1 (K), R112.2, R113.2, R114.1
unnamed: D101.1 (K), Q102.3 (C)
unnamed: D102.2 (A), Q103.3 (C)
unnamed: D103.1 (K), R117.1
unnamed: D104.2 (A), R118.1
unnamed: D105.1 (+), F101.2
unnamed: D105.4 (-), F102.2
unnamed: J101.1, R101.1
unnamed: C101.1, J101.2
unnamed: J102.2, L101.2, R109.2, R110.1, R112.1, R113.1
unnamed: C124.1, D105.3, J103.1
unnamed: C124.2, D105.2, J103.2
unnamed: Q101.2 (A2), R110.2
unnamed: Q101.3 (G), Q102.2 (E), Q103.2 (E), R111.1
unnamed: C115.1, Q102.1 (B), R114.2, R115.2, R116.2
unnamed: Q103.1 (B), R116.1
unnamed: L101.1, R105.1, R106.1, R107.1, R109.1, U101.3
unnamed: C102.1, C105.1, R103.1, U101.10 (+)
unnamed: C105.2, C106.2, R104.2, R105.2, U101.9 (-)
unnamed: C107.2, R108.2, U101.8 (MUTE)
VN: C117.2, C119.2, C121.2, C123.2, D104.1 (K), F102.1, R108.1, U101.4 (V-)
VP: C116.1, C118.1, C120.2, C122.2, D103.2 (A), F101.1, U101.1 (V+), U101.5 (V+)

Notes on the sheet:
DC 26V
supply
bandwidth -3dB 10Hz - 100kHz
47k+50uF supply 25V, load 3.5ohm 20V trip at 0.2s
DNP if electrolytic capasitors used
or mlcc 5x 0805/1206 10uF 16V
Irms 1.5A fuse 3A, 20 A^2S
AC 20V
out
0.8-1.0 uH in par to R (15 turns d 0.8mm)
Cement/Wirewound!
DNP if jumper wire used

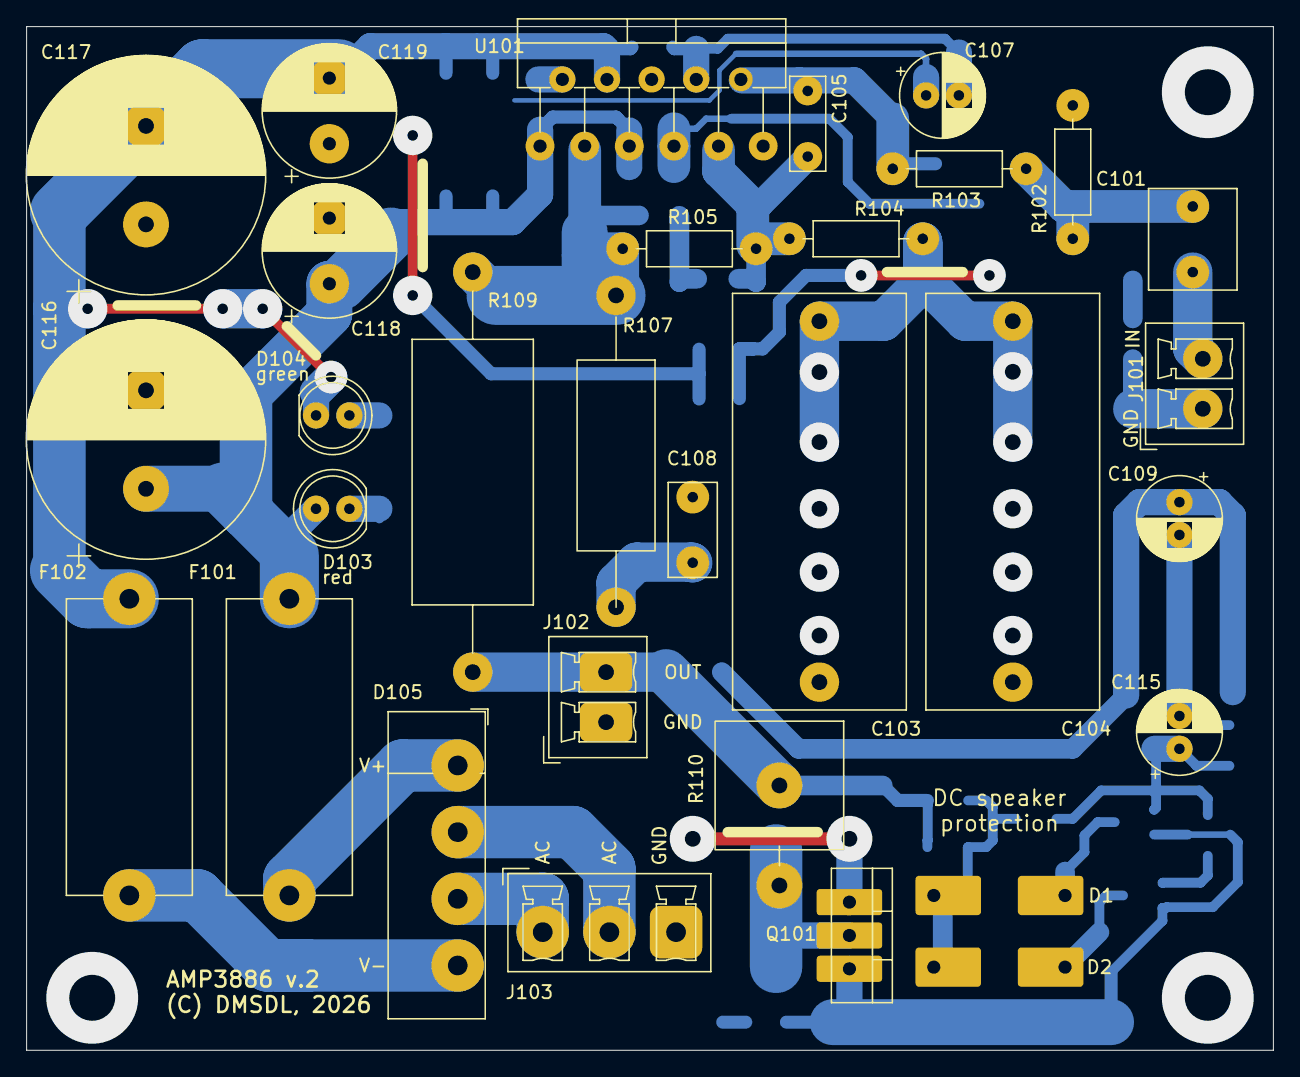
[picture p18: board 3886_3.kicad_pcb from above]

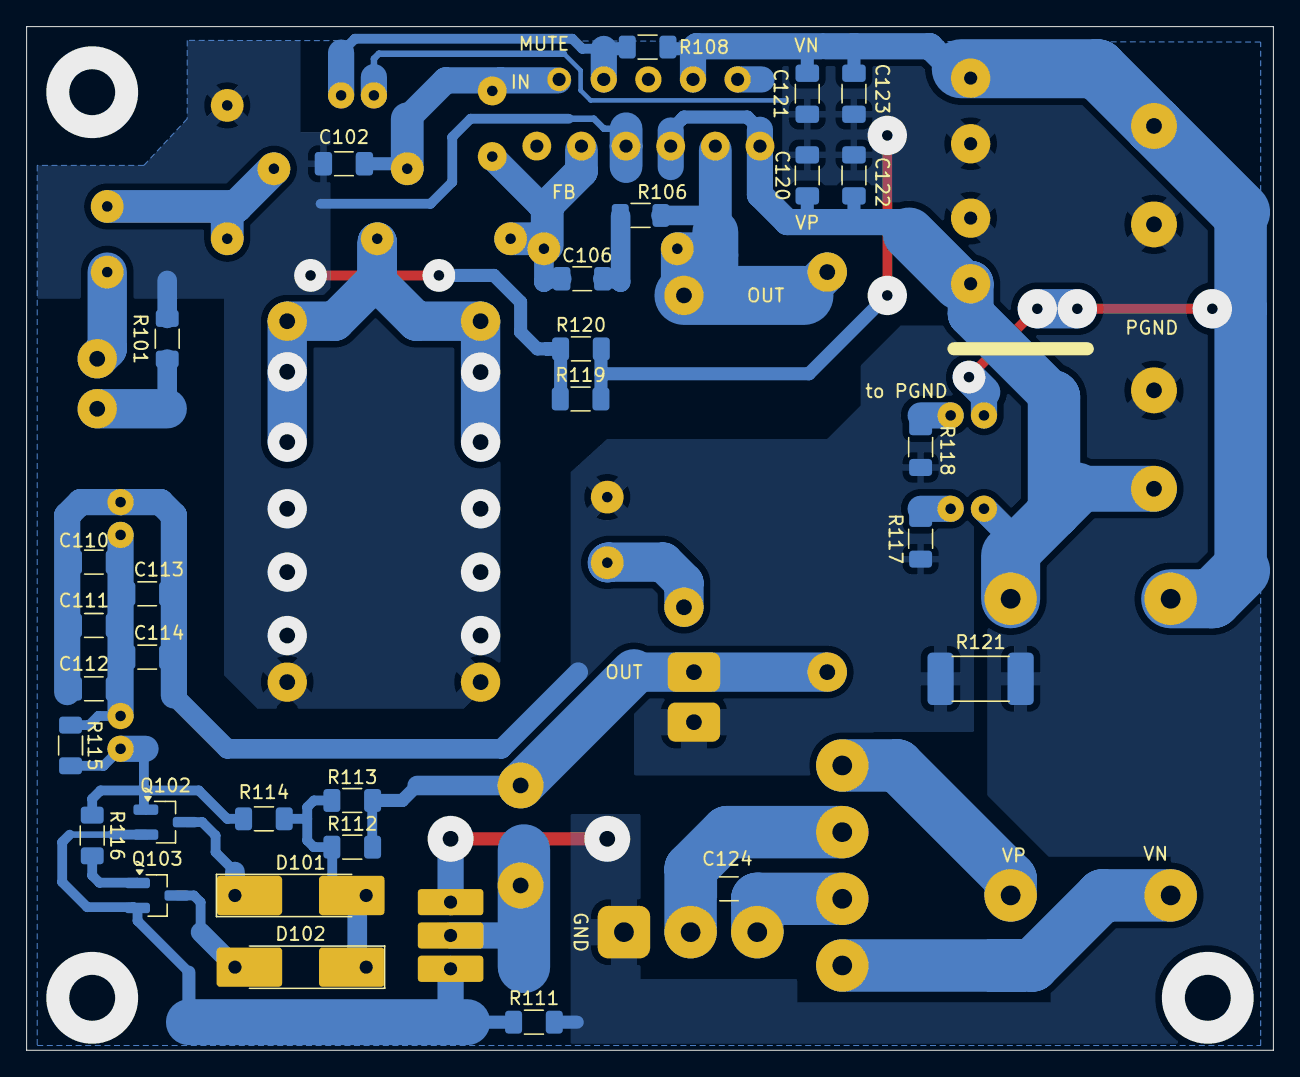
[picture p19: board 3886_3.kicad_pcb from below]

Board: 2 copper layers, 95.0 x 78.0 mm, 59 parts (30 on the bottom side), 28 nets.

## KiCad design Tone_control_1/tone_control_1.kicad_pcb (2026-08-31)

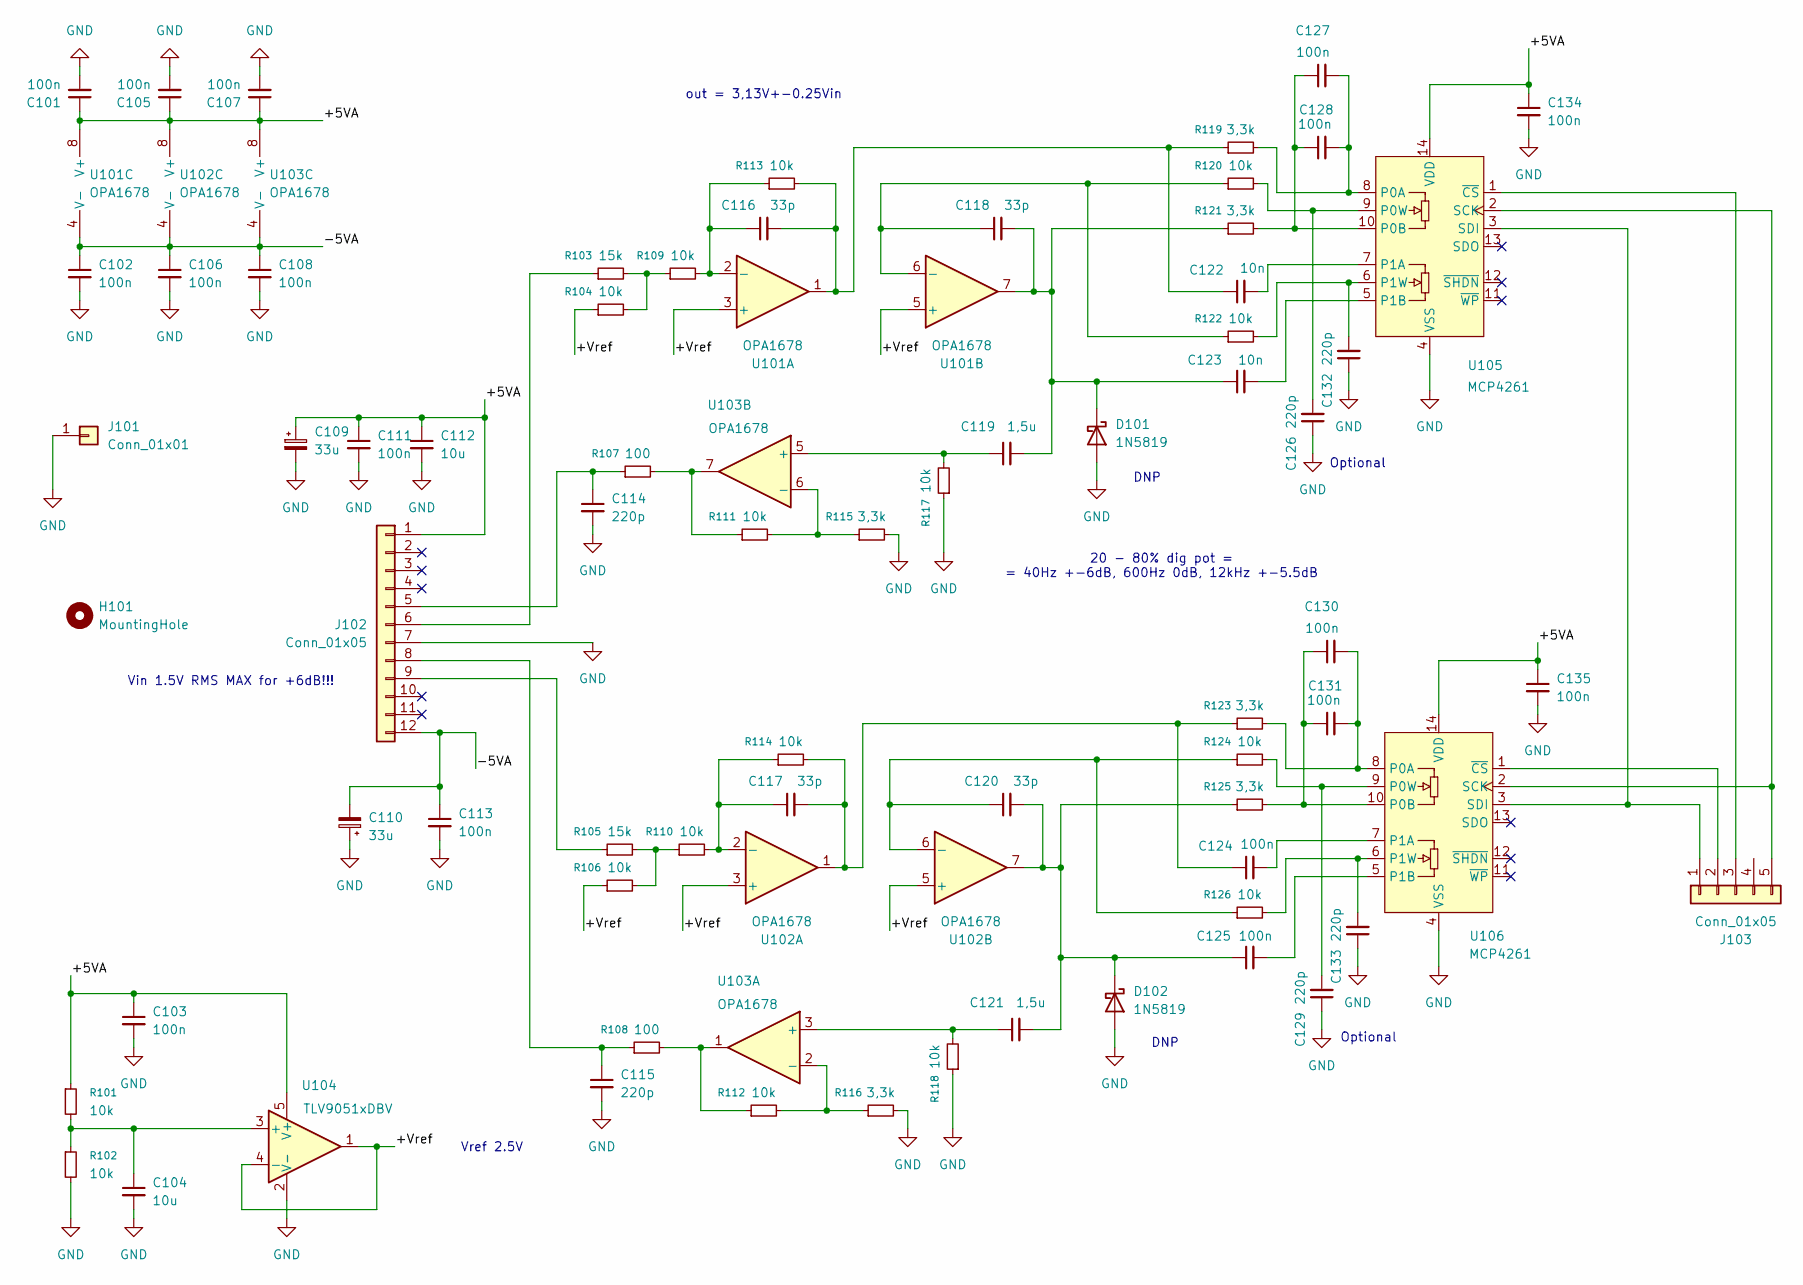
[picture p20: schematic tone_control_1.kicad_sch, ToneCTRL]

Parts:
C101, C102, C103, C105, C106, C107, C108, C111, C113, C124, C125, C134, C135: 100n; C_0805_2012Metric_Pad1.18x1.45mm_HandSolder
C104, C112: 10u; C_0805_2012Metric_Pad1.18x1.45mm_HandSolder
C109, C110: 33u; CP_EIA-6032-20_AVX-F_HandSolder
C114, C115, C126, C129, C132, C133: 220p; C_0805_2012Metric_Pad1.18x1.45mm_HandSolder
C116, C117, C118, C120: 33p; C_0805_2012Metric_Pad1.18x1.45mm_HandSolder
C119, C121: 1,5u; C_Rect_L7.5mm_W6.5mm_P5.00mm
C122, C123: 10n; C_0805_2012Metric_Pad1.18x1.45mm_HandSolder
C127, C128, C130, C131: 100n; C_1206_3216Metric_Pad1.33x1.80mm_HandSolder
D101, D102: 1N5819; D_SOD-123
H101: MountingHole; MountingHole_2.7mm_M2.5
J101: Conn_01x01; PinHeader_1x01_P2.54mm_Vertical
J102: Conn_01x05; PinSocket_1x12_P2.54mm_Vertical
J103: Conn_01x05; PinSocket_1x05_P2.54mm_Vertical
R101, R102, R104, R106, R109, R110, R111, R112, R113, R114, R117, R118, R120, R122, R124, R126: 10k; R_0805_2012Metric_Pad1.20x1.40mm_HandSolder
R103, R105: 15k; R_0805_2012Metric_Pad1.20x1.40mm_HandSolder
R107, R108: 100; R_0805_2012Metric_Pad1.20x1.40mm_HandSolder
R115, R116, R119, R121, R123, R125: 3,3k; R_0805_2012Metric_Pad1.20x1.40mm_HandSolder
U101, U102, U103: OPA1678; SOIC-8_3.9x4.9mm_P1.27mm
U104: TLV9051xDBV; SOT-23-5_HandSoldering
U105, U106: MCP4261; TSSOP-14_4.4x5mm_P0.65mm

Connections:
/+5VA: C101.1, C103.1, C105.1, C107.1, C109.1, C111.1, C112.1, C134.1, C135.1, J102.1, R101.1, U101.8 (V+), U102.8 (V+), U103.8 (V+), U104.5 (V+), U105.14 (VDD), U106.14 (VDD)
/+Vref: R104.1, R106.1, U101.3 (+), U101.5 (+), U102.3 (+), U102.5 (+), U104.1, U104.4 (-)
/-5VA: C102.1, C106.1, C108.1, C110.2, C113.1, J102.12, U101.4 (V-), U102.4 (V-), U103.4 (V-)
GND: C101.2, C102.2, C103.2, C104.2, C105.2, C106.2, C107.2, C108.2, C109.2, C110.1, C111.2, C112.2, C113.2, C114.2, C115.2, C126.1, C129.1, C132.1, C133.1, C134.2, C135.2, D101.2 (A), D102.2 (A), J101.1, J102.7, R102.2, R115.2, R116.2, R117.1, R118.1, U104.2 (V-), U105.4 (VSS), U106.4 (VSS)
unnamed: C116.2, C122.1, R113.2, R119.1, U101.1
unnamed: C117.2, C124.1, R114.2, R123.1, U102.1
unnamed: C118.2, C119.2, C123.1, D101.1 (K), R121.1, U101.7
unnamed: C120.2, C121.2, C125.1, D102.1 (K), R125.1, U102.7
unnamed: C114.1, J102.5, R107.1
unnamed: J102.6, R103.1
unnamed: C115.1, J102.8, R108.1
unnamed: J102.9, R105.1
unnamed: J103.1, U105.3 (SDI), U106.3 (SDI)
unnamed: J103.2, U106.1 (~CS)
unnamed: J103.3, U105.1 (~CS)
unnamed: J103.5, U105.2 (SCK), U106.2 (SCK)
unnamed: R103.2, R104.2, R109.1
unnamed: R105.2, R106.2, R110.1
unnamed: R107.2, R111.1, U103.7
unnamed: R108.2, R112.1, U103.1
unnamed: C116.1, R109.2, R113.1, U101.2 (-)
unnamed: C118.1, R120.1, R122.1, U101.6 (-)
unnamed: C117.1, R110.2, R114.1, U102.2 (-)
unnamed: C120.1, R124.1, R126.1, U102.6 (-)
unnamed: C121.1, R118.2, U103.3 (+)
unnamed: R112.2, R116.1, U103.2 (-)
unnamed: C119.1, R117.2, U103.5 (+)
unnamed: R111.2, R115.1, U103.6 (-)
unnamed: C104.1, R101.2, R102.1, U104.3 (+)
unnamed: C127.2, C128.2, R119.2, U105.8 (P0A)
unnamed: C127.1, C128.1, R121.2, U105.10 (P0B)
unnamed: C126.2, R120.2, U105.9 (P0W)
unnamed: C122.2, U105.7 (P1A)
unnamed: C123.2, U105.5 (P1B)
unnamed: C132.2, R122.2, U105.6 (P1W)
unnamed: C130.2, C131.2, R123.2, U106.8 (P0A)
unnamed: C130.1, C131.1, R125.2, U106.10 (P0B)
unnamed: C129.2, R124.2, U106.9 (P0W)
unnamed: C124.2, U106.7 (P1A)
unnamed: C125.2, U106.5 (P1B)
unnamed: C133.2, R126.2, U106.6 (P1W)

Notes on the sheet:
Optional
Vref 2.5V
DNP
20 - 80% dig pot = = 40Hz +-6dB, 600Hz 0dB, 12kHz +-5.5dB
Vin 1.5V RMS MAX for +6dB!!!
out = 3,13V+-0.25Vin

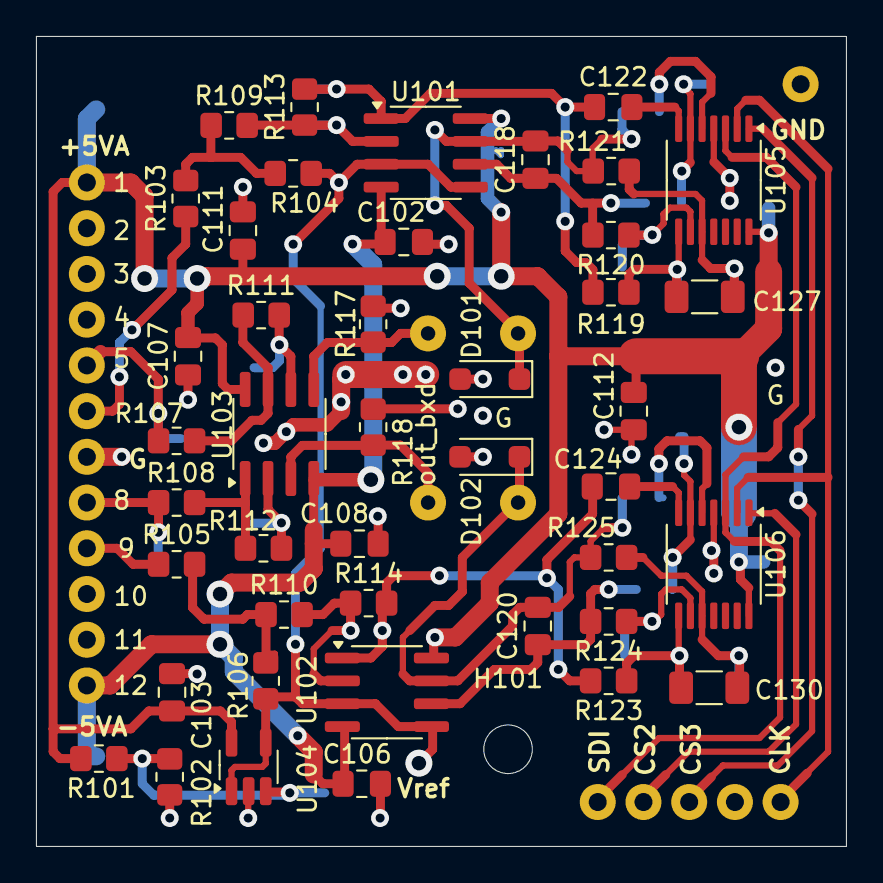
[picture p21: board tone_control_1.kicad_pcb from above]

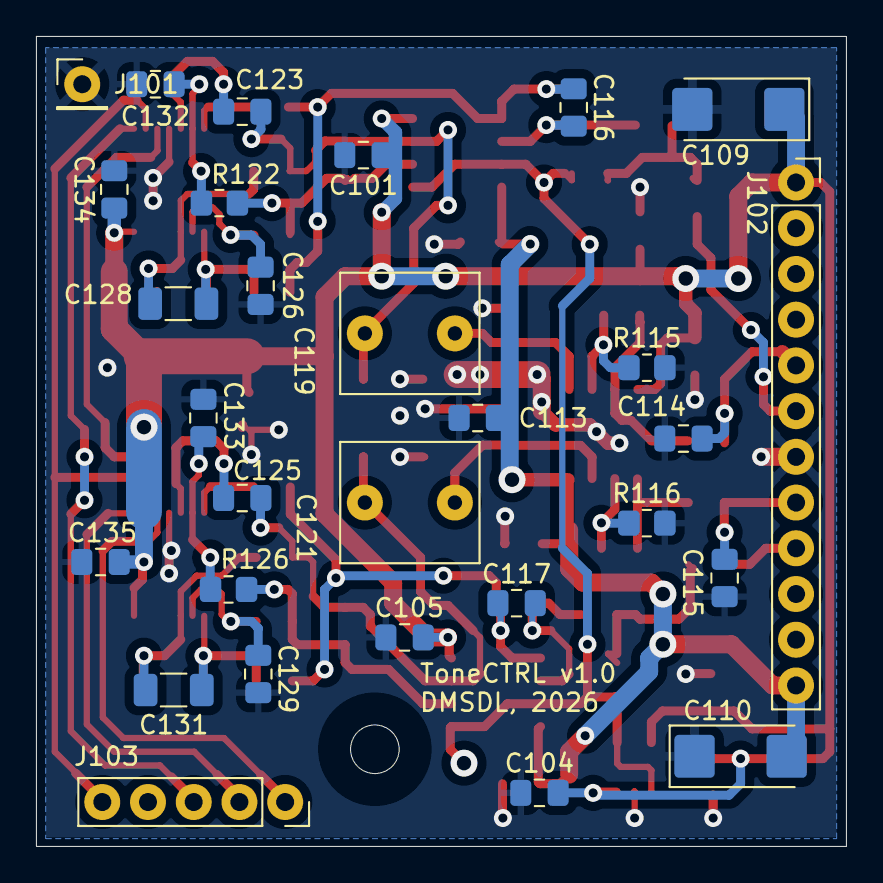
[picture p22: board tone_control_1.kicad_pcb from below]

Board: 2 copper layers, 45.0 x 45.0 mm, 73 parts (29 on the bottom side), 41 nets.

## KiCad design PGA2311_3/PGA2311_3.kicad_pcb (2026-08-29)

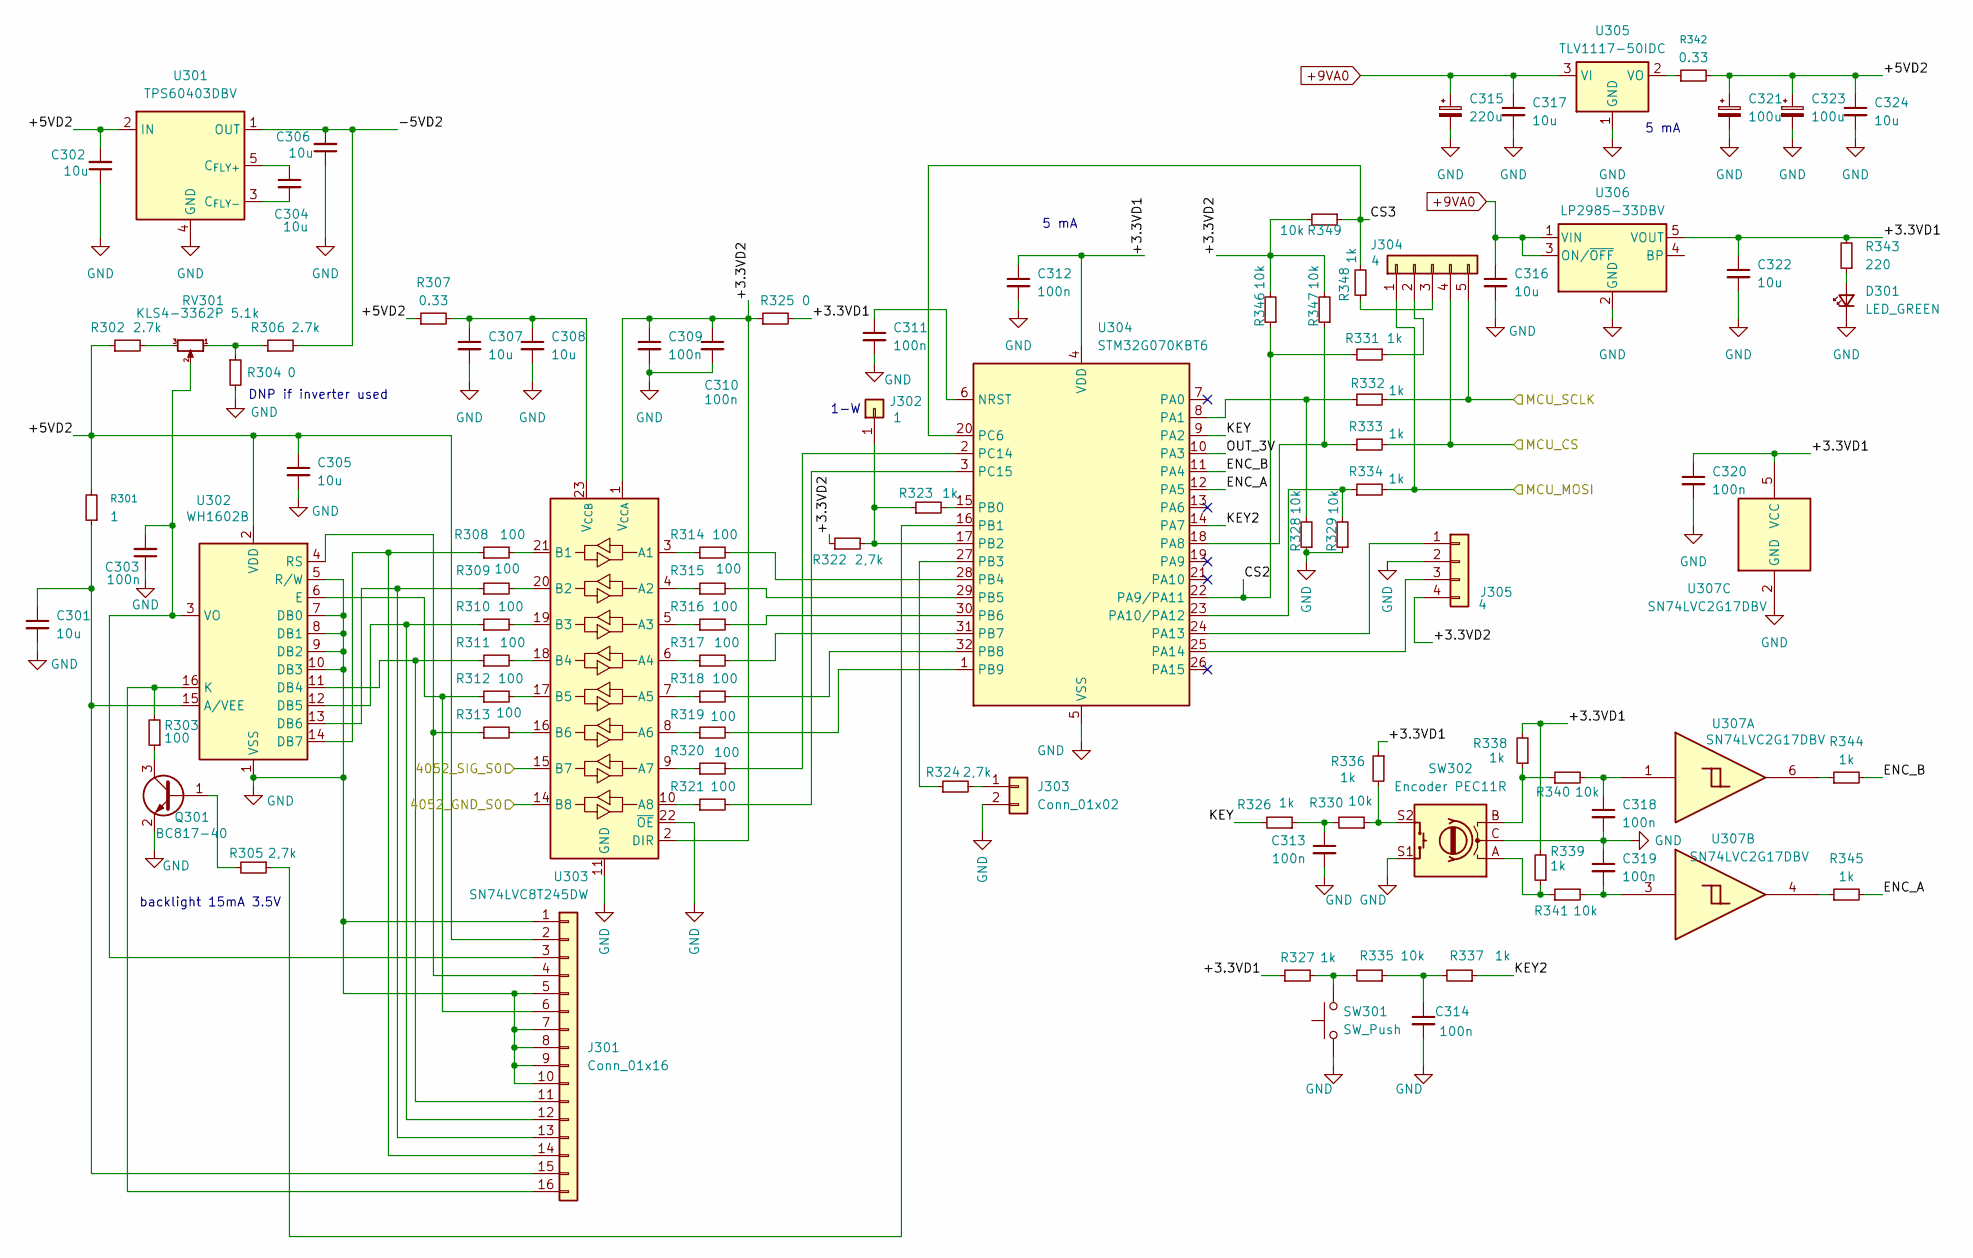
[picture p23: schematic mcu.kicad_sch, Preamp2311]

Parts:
C301, C302, C304, C305, C306, C307, C308, C316, C317, C322, C324: 10u; C_0805_2012Metric_Pad1.18x1.45mm_HandSolder
C303, C309, C310, C311, C312, C313, C314, C318, C319, C320: 100n; C_0805_2012Metric_Pad1.18x1.45mm_HandSolder
C315: 220u; CP_Radial_D8.0mm_P3.50mm
C321, C323: 100u; CP_Radial_D6.3mm_P2.50mm
D301: LED_GREEN; LED_D3.0mm
J301: Conn_01x16; PinSocket_1x16_P2.54mm_Horizontal
J302: 1; PinHeader_1x01_P2.54mm_Vertical
J303: Conn_01x02; PinHeader_1x02_P2.54mm_Vertical
J304: 4; PinHeader_1x05_P2.54mm_Vertical
J305: 4; PinHeader_1x04_P2.54mm_Vertical
Q301: BC817-40; SOT-23_Handsoldering
R301: 1; R_1206_3216Metric_Pad1.30x1.75mm_HandSolder
R302, R306: 2.7k; R_0805_2012Metric_Pad1.20x1.40mm_HandSolder
R303: 100; R_1206_3216Metric_Pad1.30x1.75mm_HandSolder
R304, R325: 0; R_0805_2012Metric_Pad1.20x1.40mm_HandSolder
R305, R322, R324: 2,7k; R_0805_2012Metric_Pad1.20x1.40mm_HandSolder
R307, R342: 0.33; R_0805_2012Metric_Pad1.20x1.40mm_HandSolder
R308, R309, R310, R311, R312, R313, R314, R315, R316, R317, R318, R319, R320, R321: 100; R_0805_2012Metric_Pad1.20x1.40mm_HandSolder
R323, R326, R327, R331, R332, R333, R334, R336, R337, R338, R339, R344, R345, R348: 1k; R_0805_2012Metric_Pad1.20x1.40mm_HandSolder
R328, R329, R330, R335, R340, R341, R346, R347, R349: 10k; R_0805_2012Metric_Pad1.20x1.40mm_HandSolder
R343: 220; R_0805_2012Metric_Pad1.20x1.40mm_HandSolder
RV301: KLS4-3362P 5.1k; Potentiometer_Vishay_T73YP_Vertical
SW301: SW_Push; SW_PUSH-12mm
SW302: Encoder PEC11R; RotaryEncoder_Alps_EC12E-Switch_Vertical_H20mm_CircularMoun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
U301: TPS60403DBV; SOT-23-5_HandSoldering
U302: WH1602B; WC1602A
U303: SN74LVC8T245DW; SOIC-24W_7.5x15.4mm_P1.27mm
U304: STM32G070KBT6; LQFP-32_7x7mm_P0.8mm
U305: TLV1117-50IDC; SOT-223-3_TabPin2
U306: LP2985-33DBV; SOT-23-5_HandSoldering
U307: SN74LVC2G17DBV; SOT-23-6_Handsoldering

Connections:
+9VA0: C315.1, C316.1, C317.1, U305.3 (VI), U306.1 (VIN), U306.3 (ON/~OFF); also elsewhere on the board
/analog/4052_GND_S0: U303.14 (B8); also elsewhere on the board
/analog/4052_SIG_S0: U303.15 (B7); also elsewhere on the board
/analog/MCU_CS: J304.4, R333.2; also elsewhere on the board
/analog/MCU_MOSI: J304.1, R334.2; also elsewhere on the board
/analog/MCU_SCLK: J304.5, R332.2; also elsewhere on the board
/mcu/+3.3VD1: C312.1, C320.1, C322.1, R325.2, R327.1, R336.1, R338.2, R339.2, R343.2, U304.4 (VDD), U306.5 (VOUT), U307.5 (VCC)
/mcu/+3.3VD2: C309.1, C310.1, J305.4, R322.1, R325.1, R346.2, R347.2, R349.2, U303.1 (V_{CCA}), U303.2 (DIR)
/mcu/+5VD2: C302.2, C305.1, C321.1, C323.1, C324.1, J301.2, R301.2, R302.1, R307.1, R342.2, U301.2 (IN), U302.2 (VDD)
/mcu/-5VD2: C306.2, R306.2, U301.1 (OUT)
/mcu/CS2: R331.2, R346.1, U304.22 (PA9/PA11)
/mcu/CS3: R348.2, R349.1, U304.20 (PC6)
/mcu/ENC_A: R345.2, U304.12 (PA5)
/mcu/ENC_B: R344.2, U304.11 (PA4)
/mcu/KEY: R326.2, U304.9 (PA2)
/mcu/KEY2: R337.1, U304.14 (PA7)
/mcu/OUT_3V: U304.10 (PA3)
GND: C301.2, C302.1, C303.1, C305.2, C306.1, C307.2, C308.2, C309.2, C310.2, C311.2, C312.2, C313.2, C314.2, C315.2, C316.2, C317.2, C318.2, C319.1, C320.2, C321.2, C322.2, C323.2, C324.2, D301.1 (K), J301.1, J301.5, J301.7, J301.8, J301.9, J301.10, J303.2, J305.2, Q301.2 (E), R304.2, R328.1, R329.1, SW301.1, SW302.C, SW302.S1, U301.4 (GND), U302.1 (VSS), U302.5 (R/W), U302.7 (DB0), U302.8 (DB1), U302.9 (DB2), U302.10 (DB3), U303.11 (GND), U303.12 (GND), U303.13 (GND), U303.22 (~OE), U304.5 (VSS), U305.1 (GND), U306.2 (GND), U307.2 (GND); also elsewhere on the board
unnamed: C307.1, C308.1, R307.2, U303.23 (V_{CCB}), U303.24 (V_{CCB})
unnamed: C313.1, R326.1, R330.2
unnamed: C314.1, R335.1, R337.2
unnamed: C318.1, R340.2, U307.1
unnamed: C319.2, R341.2, U307.3
unnamed: D301.2 (A), R343.1
unnamed: C303.2, J301.3, RV301.2, U302.3 (VO)
unnamed: J301.4, R313.1, U302.4 (RS)
unnamed: J301.6, R312.1, U302.6 (E)
unnamed: J301.11, R311.1, U302.11 (DB4)
unnamed: J301.12, R310.1, U302.12 (DB5)
unnamed: J301.13, R309.1, U302.13 (DB6)
unnamed: J301.14, R308.1, U302.14 (DB7)
unnamed: C301.1, J301.15, R301.1, U302.15 (A/VEE)
unnamed: J301.16, R303.2, U302.16 (K)
unnamed: J302.1, R322.2, R323.1, U304.17 (PB2)
unnamed: J303.1, R324.2
unnamed: J304.2, R331.1
unnamed: J304.3, R348.1
unnamed: J305.1, U304.24 (PA13)
unnamed: J305.3, U304.25 (PA14)
unnamed: Q301.1 (B), R305.2
unnamed: Q301.3 (C), R303.1
unnamed: R302.2, RV301.3
unnamed: R304.1, R306.1, RV301.1
unnamed: R327.2, R335.2, SW301.2
unnamed: R330.1, R336.2, SW302.S2
unnamed: R338.1, R340.1, SW302.B
unnamed: R339.1, R341.1, SW302.A
unnamed: R344.1, U307.6
unnamed: R345.1, U307.4
unnamed: C304.1, U301.5 (C_{FLY+})
unnamed: C304.2, U301.3 (C_{FLY-})
unnamed: R314.1, U303.3 (A1)
unnamed: R315.1, U303.4 (A2)
unnamed: R316.1, U303.5 (A3)
unnamed: R317.1, U303.6 (A4)
unnamed: R318.1, U303.7 (A5)
unnamed: R319.1, U303.8 (A6)
unnamed: R320.1, U303.9 (A7)
unnamed: R321.1, U303.10 (A8)
unnamed: R308.2, U303.21 (B1)
unnamed: R309.2, U303.20 (B2)
unnamed: R310.2, U303.19 (B3)
unnamed: R311.2, U303.18 (B4)
unnamed: R312.2, U303.17 (B5)
unnamed: R313.2, U303.16 (B6)
unnamed: C311.1, U304.6 (NRST)
unnamed: R328.2, R332.1, U304.8 (PA1)
unnamed: R333.1, R347.1, U304.18 (PA8)
unnamed: R329.2, R334.1, U304.23 (PA10/PA12)
unnamed: R323.2, U304.15 (PB0)
unnamed: R305.1, U304.16 (PB1)
unnamed: R324.1, U304.27 (PB3)
unnamed: R314.2, U304.28 (PB4)
unnamed: R315.2, U304.29 (PB5)
unnamed: R316.2, U304.30 (PB6)
unnamed: R317.2, U304.31 (PB7)
unnamed: R318.2, U304.32 (PB8)
unnamed: R319.2, U304.1 (PB9)
unnamed: R320.2, U304.2 (PC14)
unnamed: R321.2, U304.3 (PC15)
unnamed: R342.1, U305.2 (VO)

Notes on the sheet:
5 mA
DNP if inverter used
1-W
backlight 15mA 3.5V

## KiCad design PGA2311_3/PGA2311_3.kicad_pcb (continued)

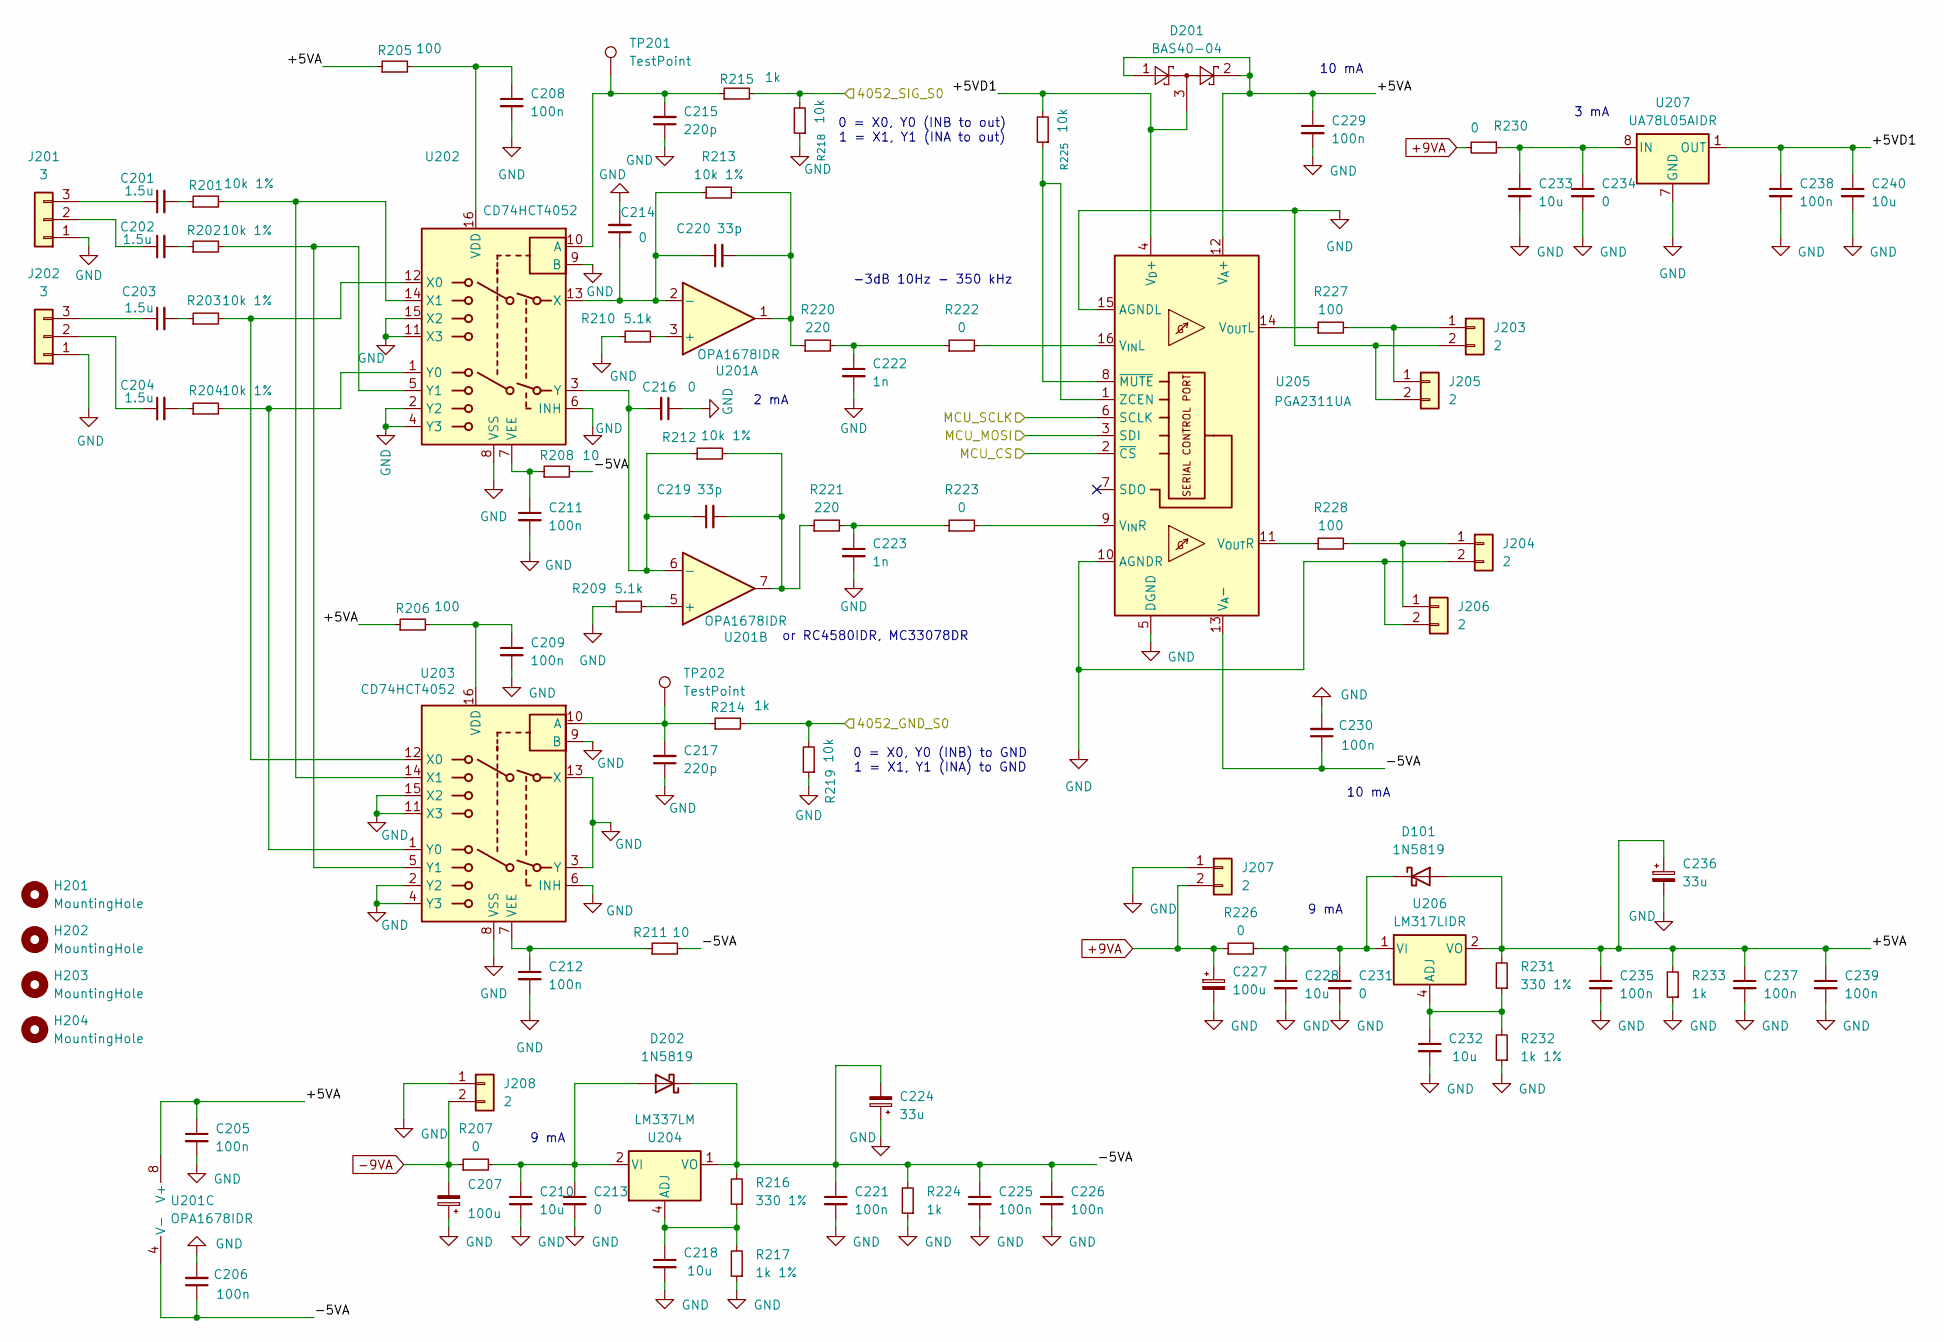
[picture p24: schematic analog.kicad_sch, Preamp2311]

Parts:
C201, C202, C203, C204: 1.5u; C_Rect_L7.2mm_W7.2mm_P5.00mm_FKS2_FKP2_MKS2_MKP2
C205, C206, C208, C209, C211, C212, C221, C225, C226, C229, C230, C235, C237, C238, C239: 100n; C_0805_2012Metric_Pad1.18x1.45mm_HandSolder
C207, C227: 100u; CP_Radial_D6.3mm_P2.50mm
C210, C218, C228, C232, C233, C240: 10u; C_0805_2012Metric_Pad1.18x1.45mm_HandSolder
C213, C214, C216, C231, C234: 0; C_0805_2012Metric_Pad1.18x1.45mm_HandSolder
C215, C217: 220p; C_0805_2012Metric_Pad1.18x1.45mm_HandSolder
C219, C220: 33p; C_0805_2012Metric_Pad1.18x1.45mm_HandSolder
C222, C223: 1n; C_0805_2012Metric_Pad1.18x1.45mm_HandSolder
C224, C236: 33u; CP_EIA-6032-20_AVX-F_HandSolder
D101, D202: 1N5819; D_SOD-123
D201: BAS40-04; SOT-23_Handsoldering
H201, H202, H203, H204: MountingHole; MountingHole_2.7mm_M2.5
J201, J202: 3; PhoenixContact_MCV_1,5_3-G-3.81_1x03_P3.81mm_Vertical
J203, J204: 2; PhoenixContact_MCV_1,5_2-G-3.81_1x02_P3.81mm_Vertical
J205, J206, J207, J208: 2; PinHeader_1x02_P2.54mm_Vertical
R201, R202, R203, R204, R212, R213: 10k 1%; R_1206_3216Metric_Pad1.30x1.75mm_HandSolder
R205, R206, R227, R228: 100; R_0805_2012Metric_Pad1.20x1.40mm_HandSolder
R207, R222, R223, R226, R230: 0; R_0805_2012Metric_Pad1.20x1.40mm_HandSolder
R208, R211: 10; R_0805_2012Metric_Pad1.20x1.40mm_HandSolder
R209, R210: 5.1k; R_0805_2012Metric_Pad1.20x1.40mm_HandSolder
R214, R215, R224, R233: 1k; R_0805_2012Metric_Pad1.20x1.40mm_HandSolder
R216, R231: 330 1%; R_0805_2012Metric_Pad1.20x1.40mm_HandSolder
R217, R232: 1k 1%; R_0805_2012Metric_Pad1.20x1.40mm_HandSolder
R218, R219, R225: 10k; R_0805_2012Metric_Pad1.20x1.40mm_HandSolder
R220, R221: 220; R_0805_2012Metric_Pad1.20x1.40mm_HandSolder
TP201, TP202: TestPoint; TestPoint_THTPad_2.0x2.0mm_Drill1.0mm
U201: OPA1678IDR; SOIC-8_3.9x4.9mm_P1.27mm
U202, U203: CD74HCT4052; SOIC-16_3.9x9.9mm_P1.27mm
U204: LM337LM; SOIC-8_3.9x4.9mm_P1.27mm
U205: PGA2311UA; SOIC-16W_7.5x10.3mm_P1.27mm
U206: LM317LIDR; SOIC-8_3.9x4.9mm_P1.27mm
U207: UA78L05AIDR; SOIC-8_3.9x4.9mm_P1.27mm

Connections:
+9VA: C227.1, J207.2, R226.1, R230.2; also elsewhere on the board
-9VA: C207.2, J208.2, R207.1; also elsewhere on the board
/analog/4052_GND_S0: R214.2, R219.2; also elsewhere on the board
/analog/4052_SIG_S0: R215.2, R218.2; also elsewhere on the board
/analog/+5VA: C205.1, C229.1, C235.1, C236.1, C237.1, C239.1, D101.2 (A), D201.1, D201.2, R205.1, R206.1, R231.2, R233.2, U201.8 (V+), U205.12 (V_{A}+), U206.2 (VO), U206.3 (VO), U206.6 (VO), U206.7 (VO)
/analog/+5VD1: C238.1, C240.1, D201.3, R225.2, U205.4 (V_{D}+), U207.1 (OUT)
/analog/-5VA: C206.1, C221.1, C224.2, C225.1, C226.1, C230.1, D202.1 (K), R208.2, R211.2, R216.2, R224.2, U201.4 (V-), U204.1 (VO), U205.13 (V_{A}-)
/analog/MCU_CS: U205.2 (~CS); also elsewhere on the board
/analog/MCU_MOSI: U205.3 (SDI); also elsewhere on the board
/analog/MCU_SCLK: U205.6 (SCLK); also elsewhere on the board
GND: C205.2, C206.2, C207.1, C208.2, C209.2, C210.2, C211.2, C212.2, C213.2, C214.2, C215.1, C216.1, C217.1, C218.2, C221.2, C222.2, C223.2, C224.1, C225.2, C226.2, C227.2, C228.2, C229.2, C230.2, C231.2, C232.2, C233.2, C234.2, C235.2, C236.2, C237.2, C238.2, C239.2, C240.2, J201.1, J202.1, J203.2, J204.2, J205.2, J206.2, J207.1, J208.1, R209.1, R210.1, R217.1, R218.1, R219.1, R224.1, R232.1, R233.1, U202.2 (Y2), U202.4 (Y3), U202.6 (INH), U202.8 (VSS), U202.9 (B), U202.11 (X3), U202.15 (X2), U203.2 (Y2), U203.3 (Y), U203.4 (Y3), U203.6 (INH), U203.8 (VSS), U203.9 (B), U203.11 (X3), U203.13 (X), U203.15 (X2), U205.5 (DGND), U205.10 (AGNDR), U205.15 (AGNDL), U207.2 (GND), U207.3 (GND), U207.6 (GND), U207.7 (GND); also elsewhere on the board
unnamed: C201.2, R201.1
unnamed: C202.2, R202.1
unnamed: C203.2, R203.1
unnamed: C204.2, R204.1
unnamed: C219.2, R212.2, R221.1, U201.7
unnamed: C220.2, R213.2, R220.1, U201.1
unnamed: C222.1, R220.2, R222.1
unnamed: C223.1, R221.2, R223.1
unnamed: C228.1, C231.1, D101.1 (K), R226.2, U206.1 (VI)
unnamed: C210.1, C213.1, D202.2 (A), R207.2, U204.2 (VI), U204.3 (VI), U204.6 (VI), U204.7 (VI)
unnamed: C202.1, J201.2
unnamed: C201.1, J201.3
unnamed: C204.1, J202.2
unnamed: C203.1, J202.3
unnamed: J203.1, J205.1, R227.2
unnamed: J204.1, J206.1, R228.2
unnamed: R210.2, U201.3 (+)
unnamed: C214.1, C220.1, R213.1, U201.2 (-), U202.13 (X)
unnamed: R209.2, U201.5 (+)
unnamed: C216.2, C219.1, R212.1, U201.6 (-), U202.3 (Y)
unnamed: C215.2, R215.1, TP201.1, U202.10 (A)
unnamed: C208.1, R205.2, U202.16 (VDD)
unnamed: C211.1, R208.1, U202.7 (VEE)
unnamed: R203.2, U202.12 (X0), U203.12 (X0)
unnamed: R201.2, U202.14 (X1), U203.14 (X1)
unnamed: R204.2, U202.1 (Y0), U203.1 (Y0)
unnamed: R202.2, U202.5 (Y1), U203.5 (Y1)
unnamed: C217.2, R214.1, TP202.1, U203.10 (A)
unnamed: C209.1, R206.2, U203.16 (VDD)
unnamed: C212.1, R211.1, U203.7 (VEE)
unnamed: C218.1, R216.1, R217.2, U204.4 (ADJ)
unnamed: R222.2, U205.16 (V_{IN}L)
unnamed: R223.2, U205.9 (V_{IN}R)
unnamed: R227.1, U205.14 (V_{OUT}L)
unnamed: R228.1, U205.11 (V_{OUT}R)
unnamed: R225.1, U205.1 (ZCEN), U205.8 (~MUTE)
unnamed: C232.1, R231.1, R232.2, U206.4 (ADJ)
unnamed: C233.1, C234.1, R230.1, U207.8 (IN)

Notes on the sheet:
9 mA
3 mA
10 mA
0 = X0, Y0 (INB) to GND 1 = X1, Y1 (INA) to GND
0 = X0, Y0 (INB to out) 1 = X1, Y1 (INA to out)
2 mA
-3dB 10Hz - 350 kHz
or RC4580IDR, MC33078DR

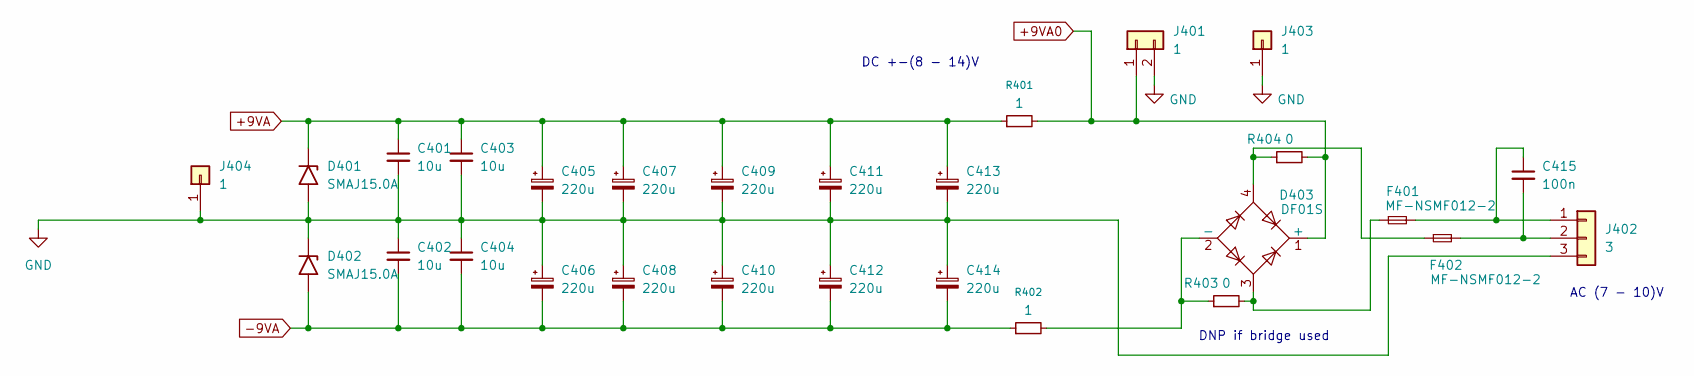
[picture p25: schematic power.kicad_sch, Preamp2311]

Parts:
C401, C402, C403, C404: 10u; C_0805_2012Metric_Pad1.18x1.45mm_HandSolder
C405, C406, C407, C408, C409, C410, C411, C412, C413, C414: 220u; CP_Radial_D8.0mm_P3.50mm
C415: 100n; C_1206_3216Metric_Pad1.33x1.80mm_HandSolder
D401, D402: SMAJ15.0A; D_SMB
D403: DF01S; Diode_Bridge_OnSemi_SDIP-4L
F401, F402: MF-NSMF012-2; Fuse_1206_3216Metric
J401: 1; PinHeader_1x02_P2.54mm_Vertical
J402: 3; PhoenixContact_MCV_1,5_3-G-3.81_1x03_P3.81mm_Vertical
J403, J404: 1; PinHeader_1x01_P2.54mm_Vertical
R401, R402: 1; R_1206_3216Metric_Pad1.30x1.75mm_HandSolder
R403, R404: 0; R_1206_3216Metric_Pad1.30x1.75mm_HandSolder

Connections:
+9VA: C401.1, C403.1, C405.1, C407.1, C409.1, C411.1, C413.1, D401.1 (A1), R401.1; also elsewhere on the board
+9VA0: D403.1 (+), J401.1, R401.2, R404.2; also elsewhere on the board
-9VA: C402.2, C404.2, C406.2, C408.2, C410.2, C412.2, C414.2, D402.2 (A2), R402.1; also elsewhere on the board
GND: C401.2, C402.1, C403.2, C404.1, C405.2, C406.1, C407.2, C408.1, C409.2, C410.1, C411.2, C412.1, C413.2, C414.1, D401.2 (A2), D402.1 (A1), J401.2, J402.3, J403.1, J404.1; also elsewhere on the board
unnamed: D403.2 (-), R402.2, R403.1
unnamed: D403.3, F401.1, R403.2
unnamed: D403.4, F402.1, R404.1
unnamed: C415.1, F401.2, J402.1
unnamed: C415.2, F402.2, J402.2

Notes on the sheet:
DNP if bridge used
AC (7 - 10)V
DC +-(8 - 14)V

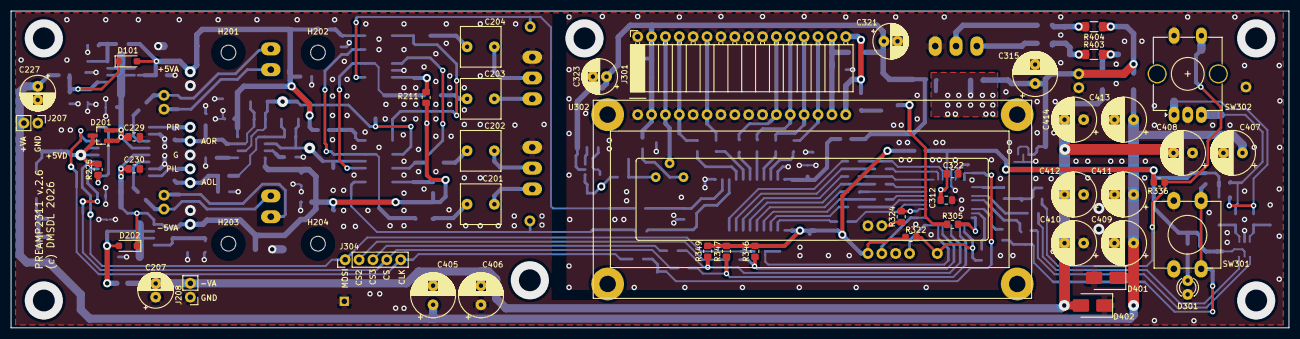
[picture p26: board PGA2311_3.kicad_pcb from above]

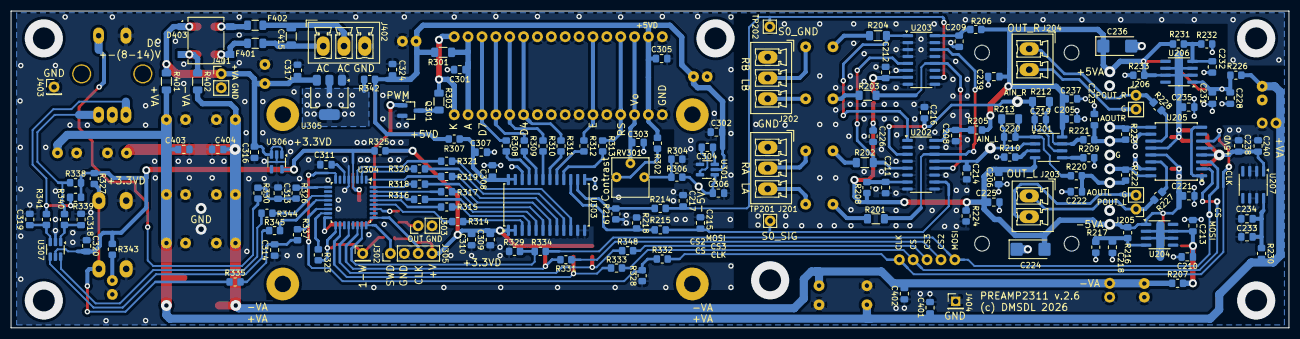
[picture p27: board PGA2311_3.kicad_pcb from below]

Board: 2 copper layers, 234.0 x 58.0 mm, 214 parts (163 on the bottom side), 128 nets.

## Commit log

2026-08-05 Add files via upload
    output connector GND corrected
    [PGA2311_3.kicad_pcb, positions.csv]
2026-08-07 Add files via upload
    Mounting holes adjusted
    [PGA2311_3.kicad_pcb, positions.csv]
2026-08-08 Add files via upload
    lm337 load resistor moved, pga2311 output resistor moved
    [PGA2311_3.kicad_pcb, positions.csv]
2026-08-11 Add files via upload
    added pull-up resistor for CS lines
    [PGA2311_3.kicad_pcb, bom.csv, designators.csv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]
2026-08-12 Add files via upload
    SPI connector changed to 5-pin
    [PGA2311_3.kicad_pcb, bom.csv, mcu.kicad_sch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]
2026-08-13 Add files via upload
    CS3 line added to connector
    [PGA2311_3.kicad_pcb, PGA2311_3.kicad_sch, analog.kicad_sch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]
2026-08-14 Add files via upload
    PGA output connector added
    [PGA2311_3.kicad_pcb, PGA2311_3.kicad_sch, analog.kicad_sch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]
2026-08-15 Add files via upload
    vias rearranged for connector placement
    [PGA2311_3.csv, PGA2311_3.kicad_pcb, PGA2311_3.kicad_sch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]
2026-08-16 Add files via upload
    v.2.4 connector to +VA line added
    [PGA2311_3.csv, PGA2311_3.kicad_pcb, PGA2311_3.kicad_sch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]
2026-08-17 Add files via upload
    78l05 output R0 removed
    [PGA2311_3.kicad_pcb, analog.kicad_sch, bom.csv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]
2026-08-19 Add files via upload
    v2.5
    [PGA2311_3.kicad_pcb, PGA2311_3.kicad_sch, analog.kicad_sch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]
2026-08-22 Add files via upload
    mounting holes changed from 2.5 to 2.7
    [PGA2311_3.csv, PGA2311_3.kicad_pcb, positions.csv]
2026-08-24 Add files via upload
    v2.6 +-5V output capacitor increased and reverse diodes added
    [PGA2311_3.kicad_pcb, PGA2311_3.kicad_sch, analog.kicad_sch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]
2026-08-24 Add files via upload
    mounting holes pad clearance increased
    [PGA2311_3.kicad_pcb]
2026-09-01 Add files via upload
    mounting holes changed from 4 to 3.5
    [3886_3.kicad_pcb]
2026-10-12 Add files via upload
    mounting holes changed
